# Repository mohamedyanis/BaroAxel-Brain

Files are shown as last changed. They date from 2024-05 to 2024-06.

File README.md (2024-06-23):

# BaroAxel Brain

StandWithPalestineBadgeBordered (https://techforpalestine.org/learn-more)




This Printed Circuit Board (PCB) is based on the STM32 microcontroller as well as MEMS sensors (MPU6050 and BMP280).
The PCB is designed using the free and open source software <a href="https://github.com/KiCad">KiCad</a>. 

## More Details
BaroAxel Brain is a compact Printed Circuit Board (PCB) designed for industrial instrumentation applications. It integrates the STM32L0 series microcontroller, MPU6050 accelerometer, and BMP280 barometer, providing a comprehensive solution for asynchronous motor anomaly detection and other MEMS-based applications.

This board operates with a wide input voltage range from 4.75V to 12V, ensuring compatibility with various power sources commonly found in industrial environments. It features multiple connectors for UART communication, analog-to-digital conversion, and timer functions, offering flexibility for interfacing with diverse sensors and peripherals.

The STM32L0 MCU, renowned for its low-power operation and high-performance computing capabilities, drives the board's functionality. The integrated MPU6050 accelerometer enables precise measurement of acceleration, essential for monitoring vibrations and detecting anomalies in industrial machinery. Additionally, the BMP280 barometer facilitates accurate measurement of atmospheric pressure, enabling environmental monitoring in diverse industrial settings.

The compact design of BaroAxel Brain optimizes space utilization, making it suitable for integration into space-constrained industrial systems while maximizing functionality. It also includes an SWD connector for firmware updates, ensuring easy maintenance and scalability of the board.

This combination of features makes BaroAxel Brain an ideal choice for applications requiring robust industrial instrumentation, such as asynchronous motor anomaly detection and drone instrumentation, among others.

This board is designed back to 2021, ordered in 2023, and hand soldered in April 2024<br><br>

## Features :dart:
* [x] Four layers PCB
* [x] Low power
* [x] Small size (50x50mm)
* [x] Very easy to use

## Thank _You_!
Please :star: this repo to help us improve the quality.
<br><br>

## PCB Block Diagram
PCB System Block
:---------------------:
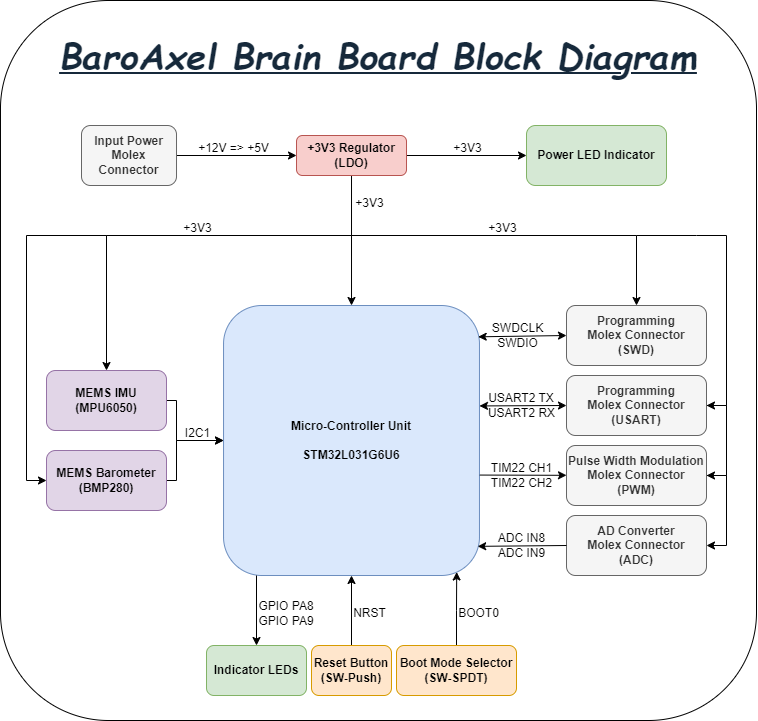
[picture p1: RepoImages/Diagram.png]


## 3D Viewer
Front View           | Back View
:---------------------:|:------------------:
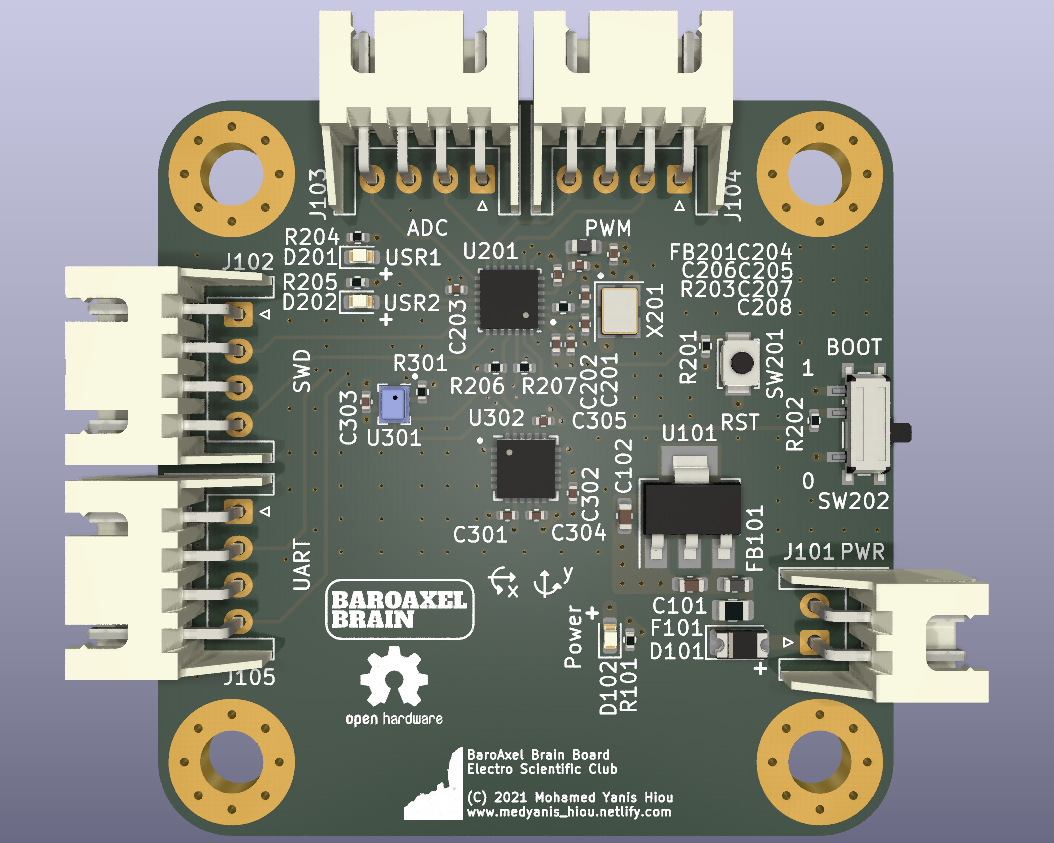
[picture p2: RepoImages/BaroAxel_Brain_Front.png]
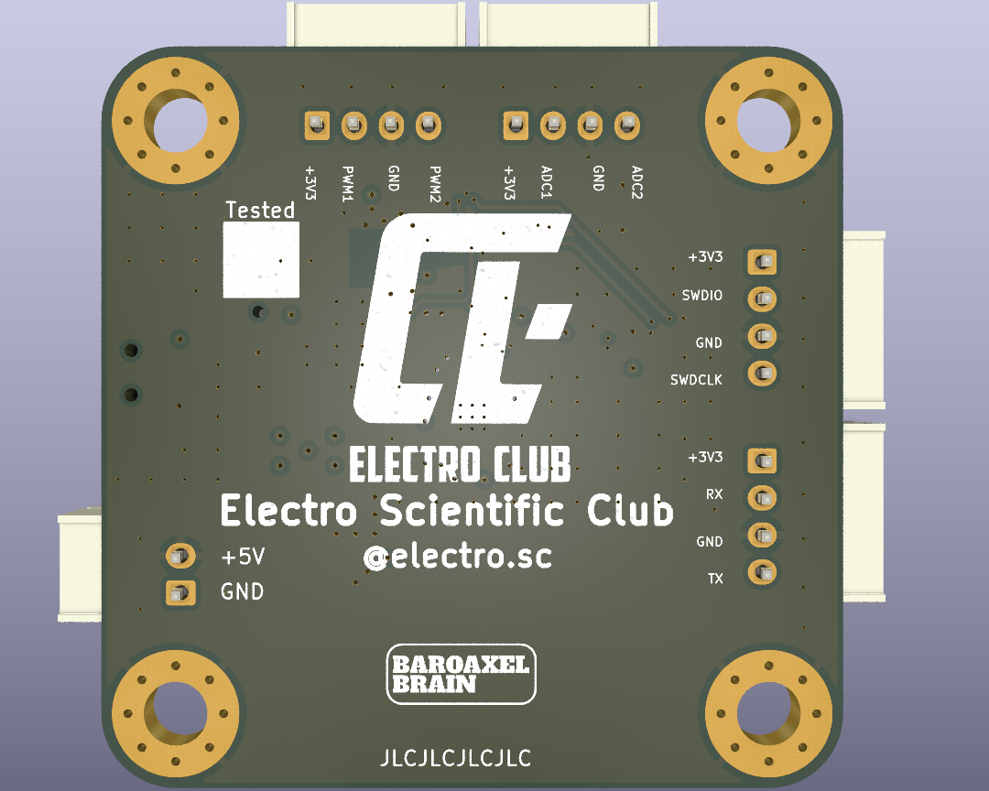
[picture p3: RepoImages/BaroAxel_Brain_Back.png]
 | 
Side View 1         |  Side View 2
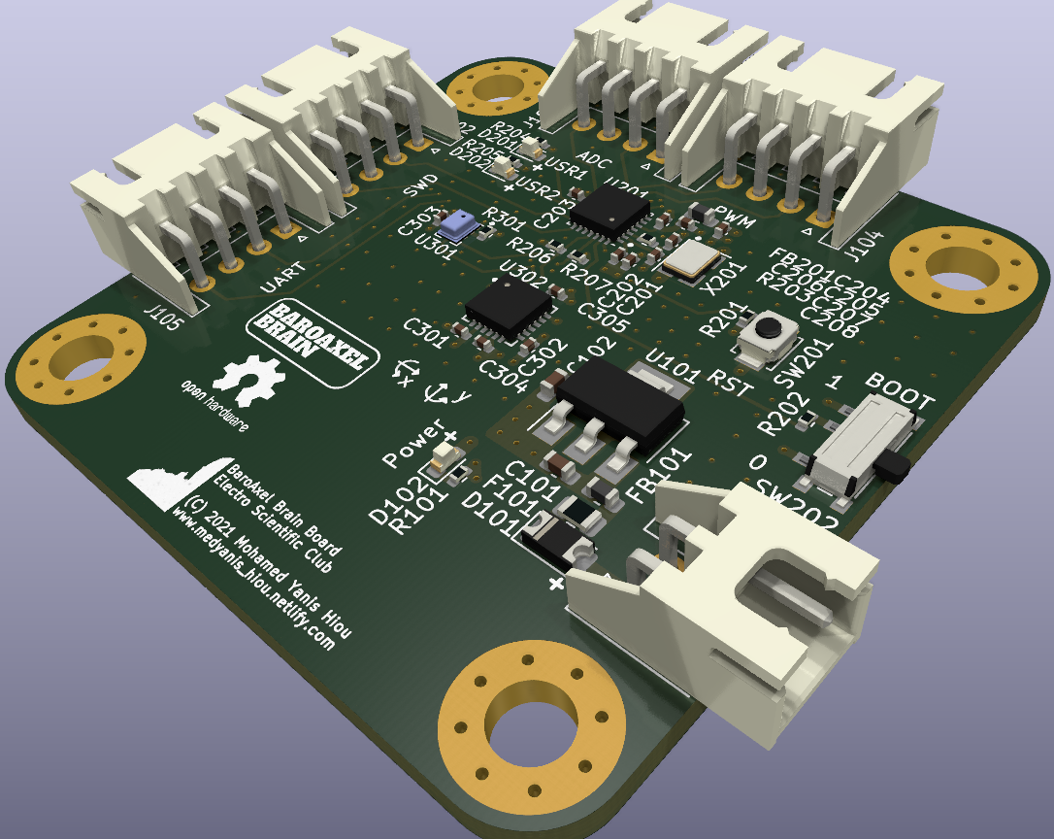
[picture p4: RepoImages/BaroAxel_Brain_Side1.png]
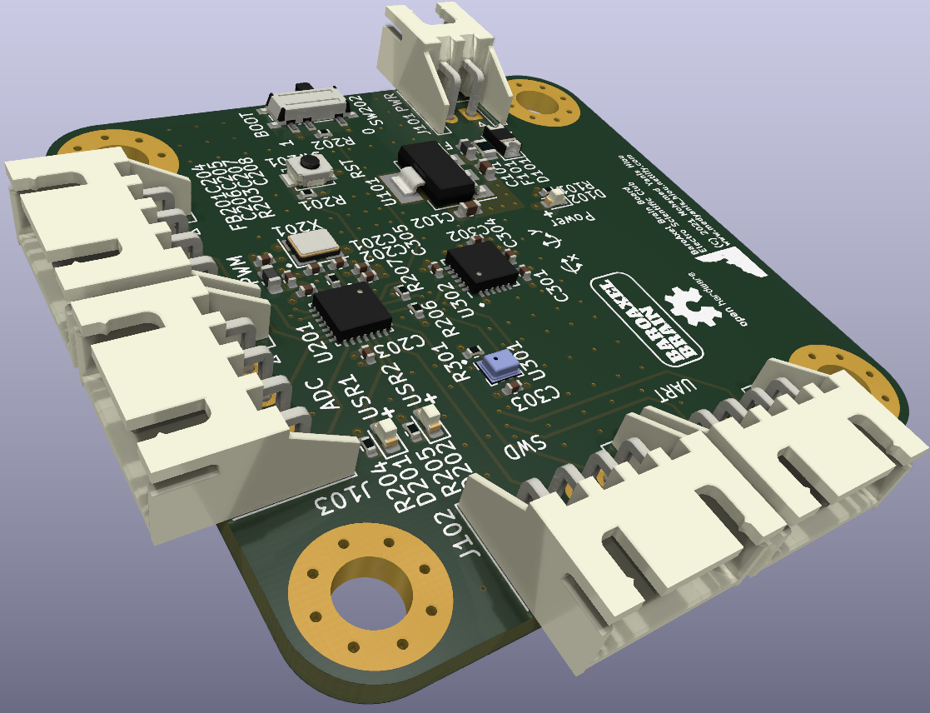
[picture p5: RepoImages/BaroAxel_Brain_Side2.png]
 | 
Side View 3         |  Side View 4
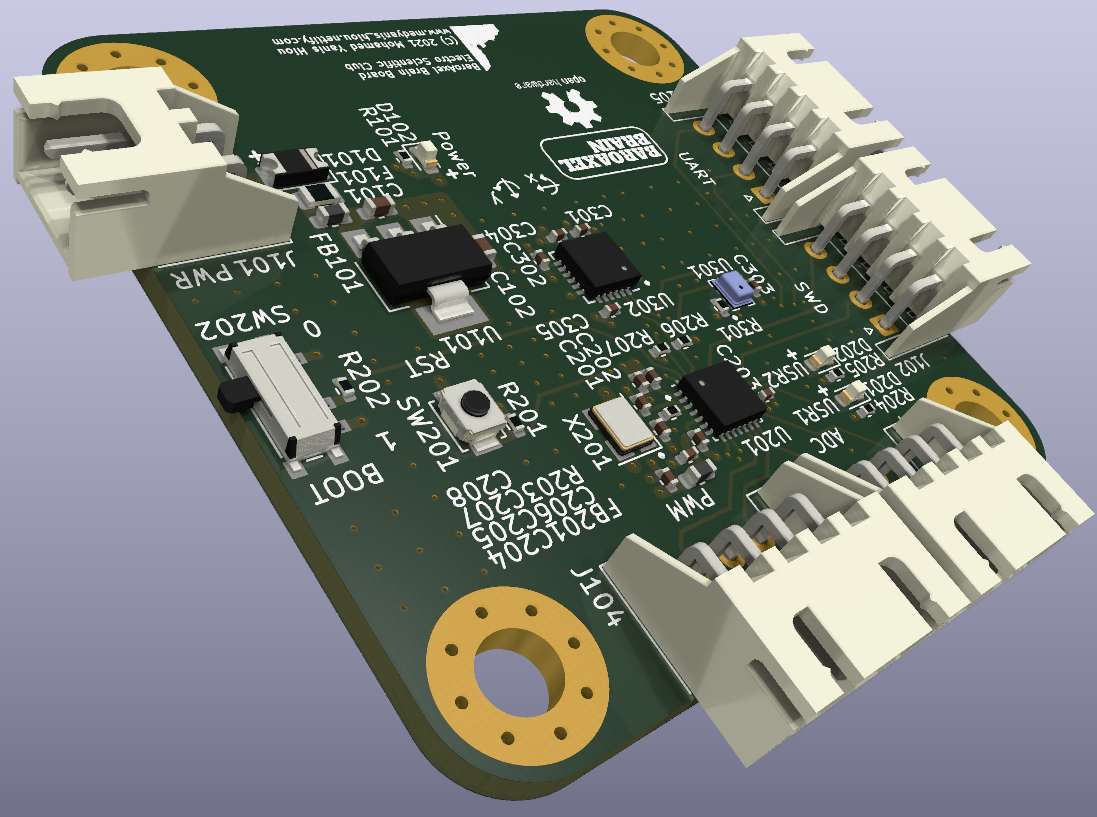
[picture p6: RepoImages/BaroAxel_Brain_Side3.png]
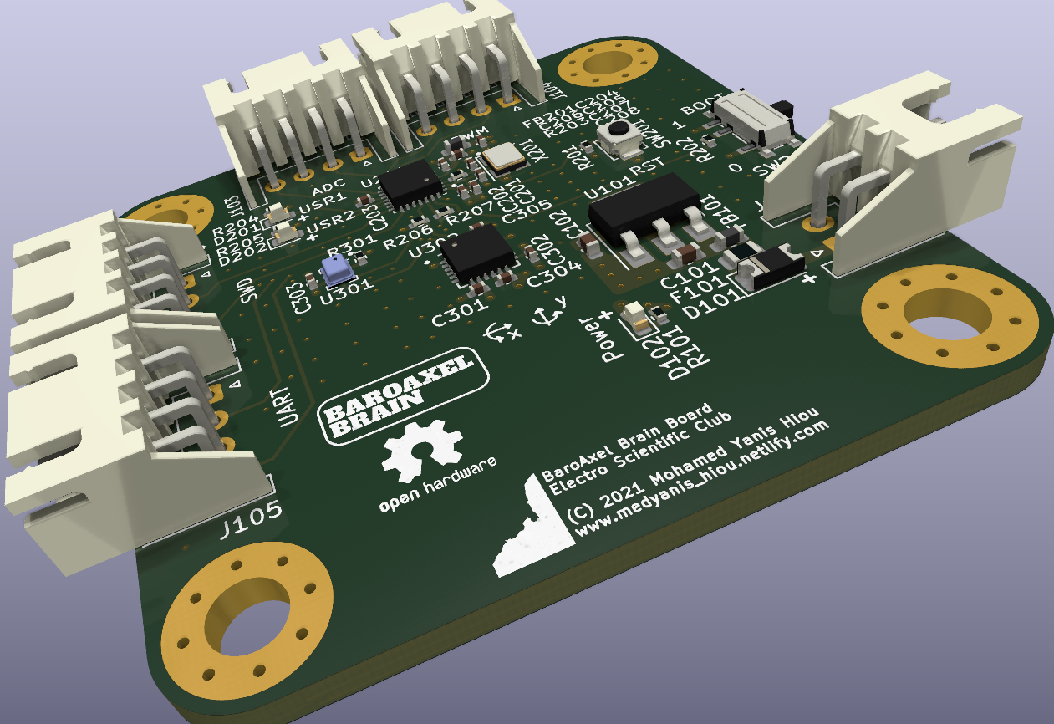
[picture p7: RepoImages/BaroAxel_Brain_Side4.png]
 | 

## Before, During and After Soldering
Before 1            | Before 2
:---------------------:|:------------------:
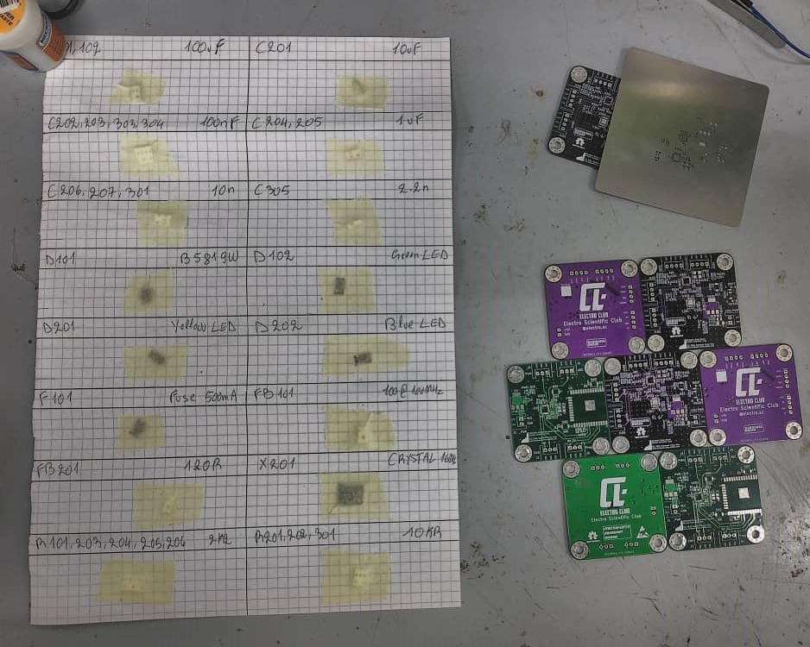
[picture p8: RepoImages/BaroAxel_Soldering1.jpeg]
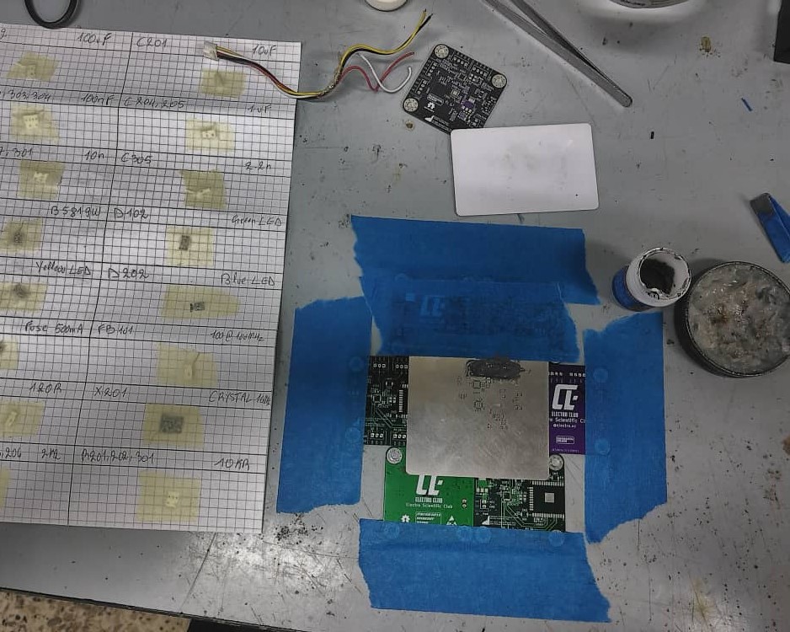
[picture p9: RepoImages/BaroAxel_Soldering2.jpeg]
 | 
During 1         |  During 2
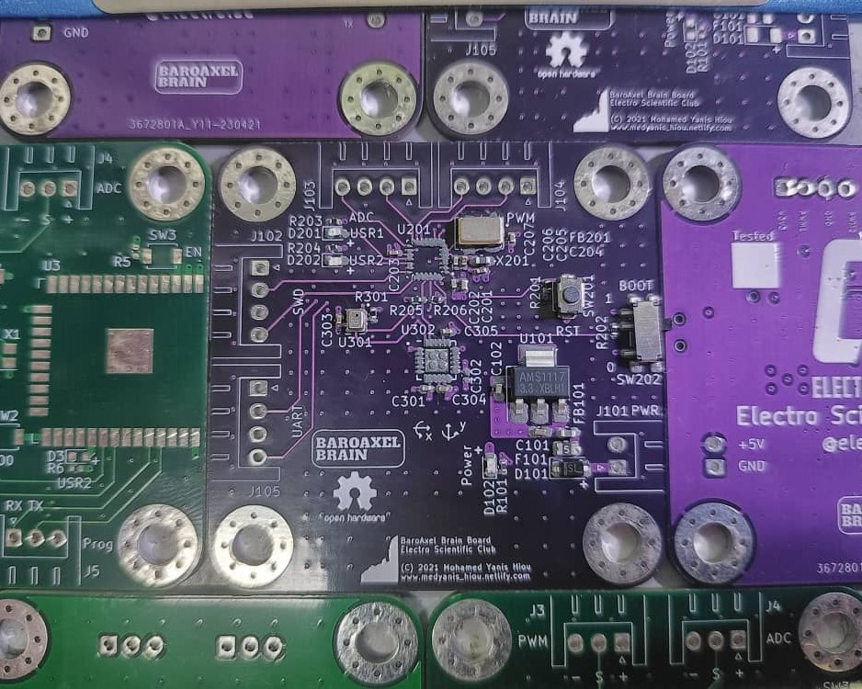
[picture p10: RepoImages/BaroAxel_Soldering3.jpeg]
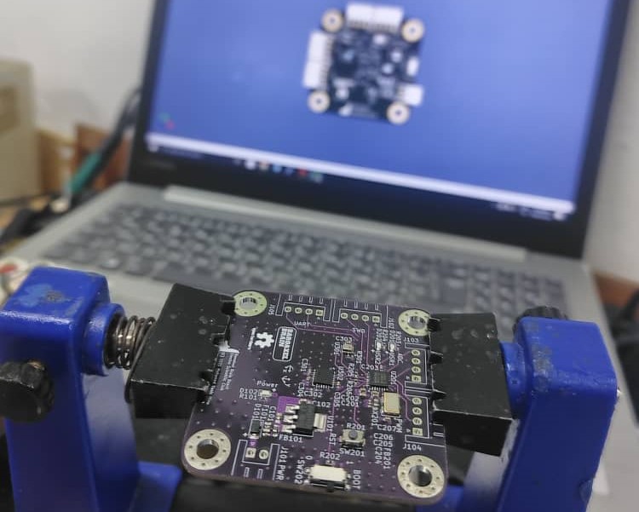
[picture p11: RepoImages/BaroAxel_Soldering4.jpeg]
 | 
After 1         |  After 2
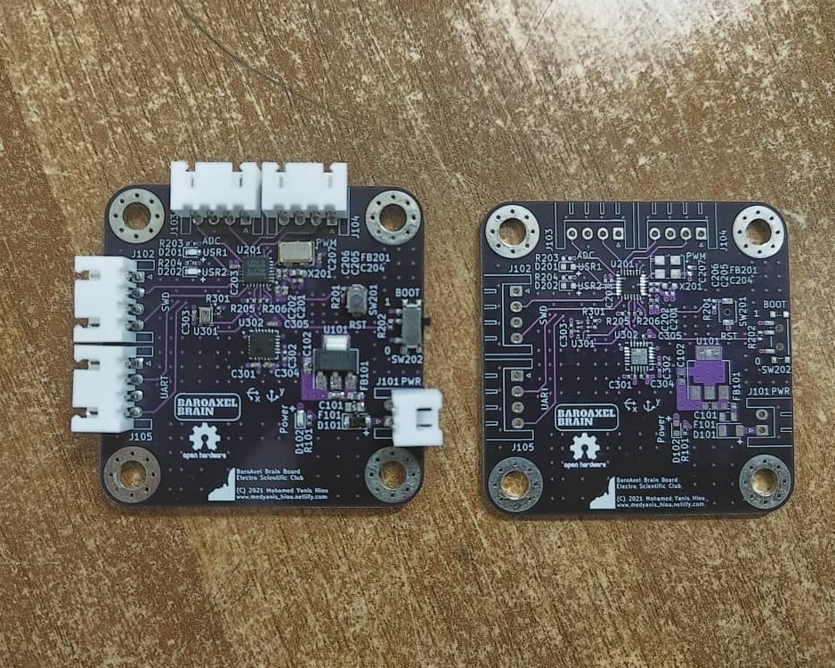
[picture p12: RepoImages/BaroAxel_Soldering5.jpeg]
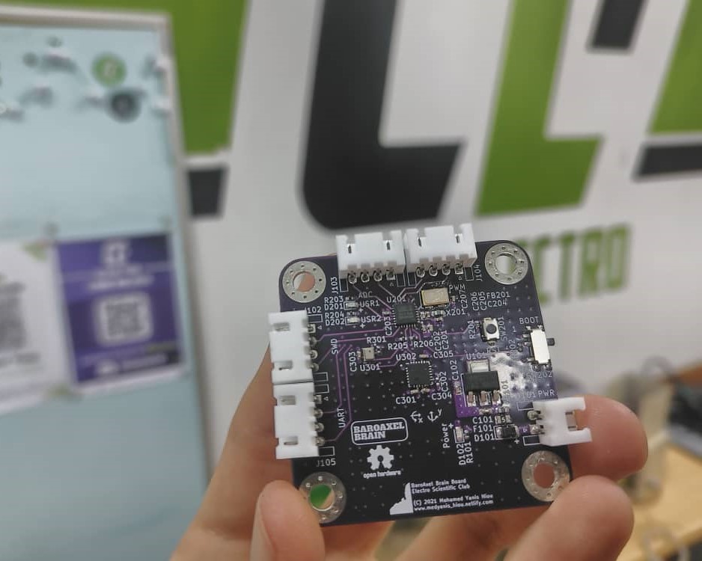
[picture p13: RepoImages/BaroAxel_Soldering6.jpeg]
 | 

## Testing the Functionality
Here I tested the functionality of the board after assembling it. I tested the built-in LEDs and the IMU (MPU6050) using I2C protocol, and print some texts on the laptop's screen using putty application via the UART-TTL converter.<br><br>


## 3D Enclosure Design
Here is the 3D Enclosure I designed using SolidWorks. The design contains the top and bottom pieces as well as a small glass plate just to show the electronics inside. Of course assembled with SolidWorks Assembly.
See the folder [3D](3D) in order to get the designs and print the parts using a 3D Printer.<br><br>
Enclosure Top           | Enclosure Bottom
:---------------------:|:------------------:
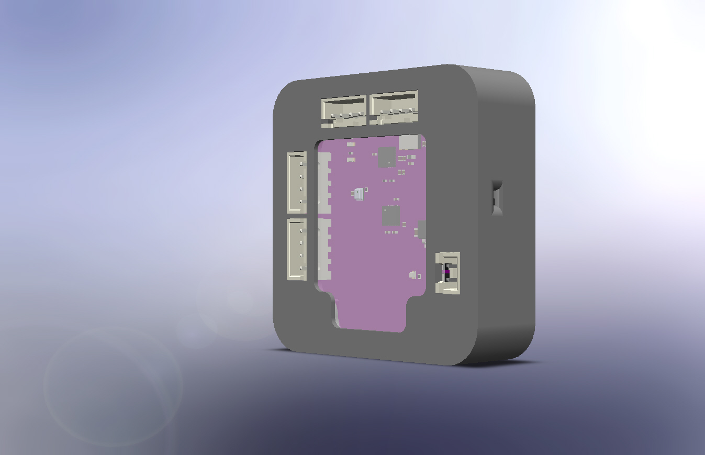
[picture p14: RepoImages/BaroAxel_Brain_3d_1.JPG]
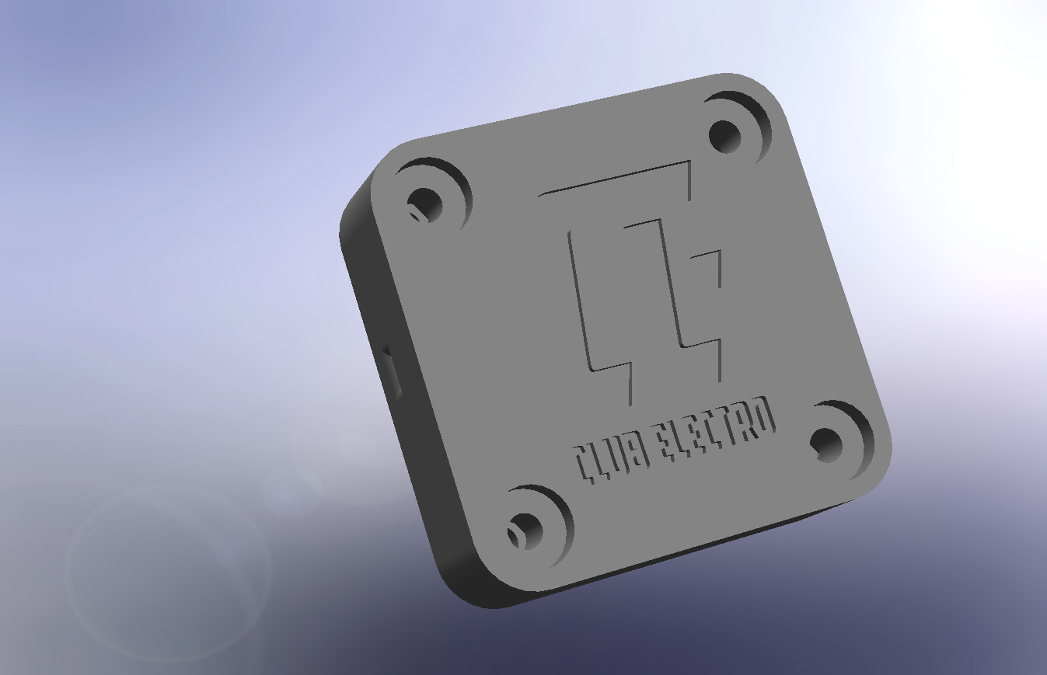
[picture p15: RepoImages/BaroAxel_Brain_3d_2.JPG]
 | 
Enclosure Side 1         |  Enclosure Side 2
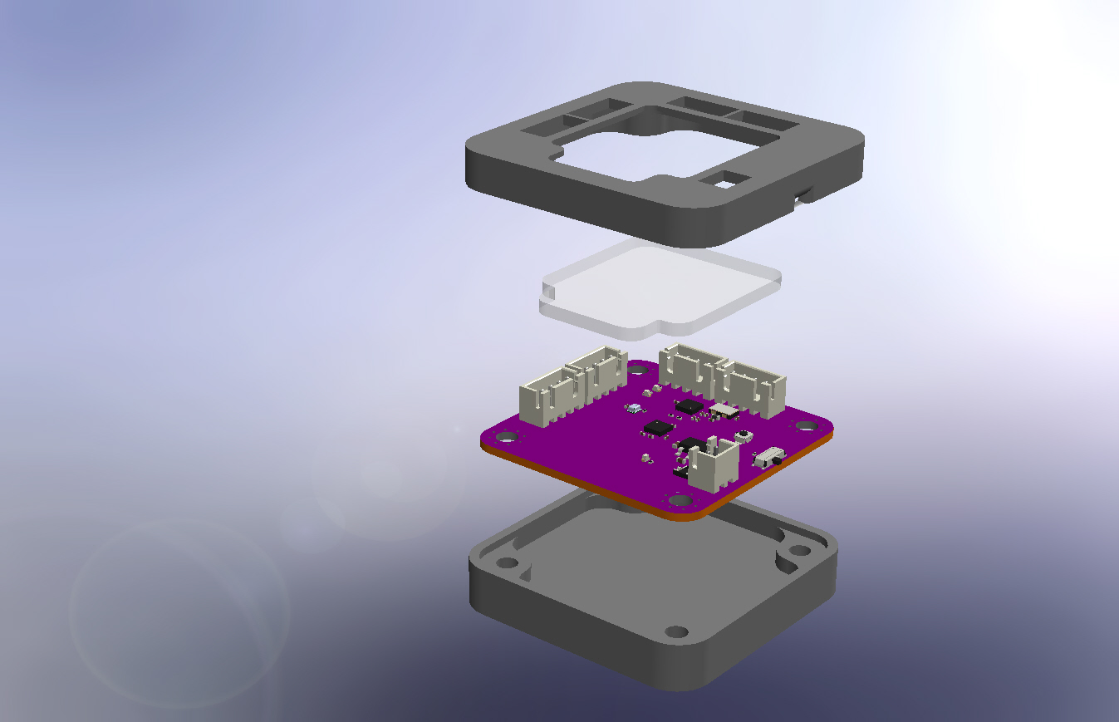
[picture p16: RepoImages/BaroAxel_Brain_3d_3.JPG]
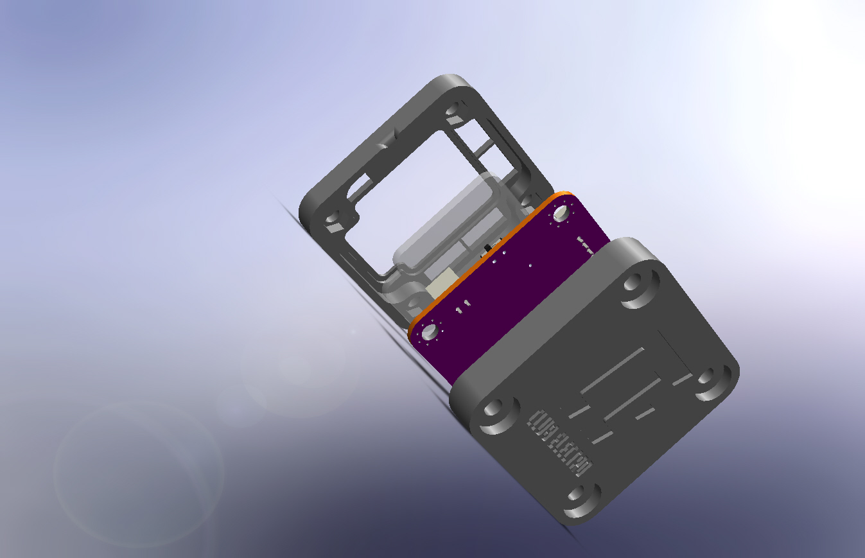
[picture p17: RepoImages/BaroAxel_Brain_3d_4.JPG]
 | 

## Requirements

If you want to review the PCB or yoou wanna edit the schematics/layout, yoou only need to install KiCad software to your machine.

* Go to the <a href="https://www.kicad.org/download/">Official KiCad Download Page</a>.
* Select your operating system.
* Download the executable file and install it.

## Documentations
Open the [Datasheets](Datasheets) folder and you will find all the datasheets, applications notes, and design guidelines that help you understand the design better.

## How To Use It

1. Install this repository, click <a href="https://github.com/mohamedyanis/BaroAxel-Brain/archive/master.zip"> here </a> to install it. Or use git command:
```bach
git clone https://github.com/mohamedyanis/BaroAxel-Brain.git
```
3. Extract the folder and open it.
4. Navigate for the [Manufacturing](Manufacturing) folder.
5. Go to your best PCB manufacturer website and click on quote.
6. Upload the [BaroAxel_Brain_Gerber.rar](Manufacturing/Gerber/BaroAxel_Brain_Gerber.zip) in order to order the board.

## License
The content of this project is licenced under the [BSD 3-Clause "New" or "Revised" License](LICENSE).

## Contributing 💡
If you want to contribute to this project and make it better with new ideas, your pull request is very welcomed.<br>
If you find any issue just put it in the repository issue section, thanks!<br><br>
.سبحَانَكَ اللَّهُمَّ وَبِحَمْدِكَ، أَشْهَدُ أَنْ لا إِلهَ إِلأَ انْتَ أَسْتَغْفِرُكَ وَأَتْوبُ إِلَيْكَ

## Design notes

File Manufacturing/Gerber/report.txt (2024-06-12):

Plotted to 'F:\Documents\Kicad\KiCad 6\BaroAxel_Brain_Board\Manufacturing\Gerber\BaroAxel_Brain-F_Cu.gbr'.
Plotted to 'F:\Documents\Kicad\KiCad 6\BaroAxel_Brain_Board\Manufacturing\Gerber\BaroAxel_Brain-In1_Cu.gbr'.
Plotted to 'F:\Documents\Kicad\KiCad 6\BaroAxel_Brain_Board\Manufacturing\Gerber\BaroAxel_Brain-In2_Cu.gbr'.
Plotted to 'F:\Documents\Kicad\KiCad 6\BaroAxel_Brain_Board\Manufacturing\Gerber\BaroAxel_Brain-B_Cu.gbr'.
Plotted to 'F:\Documents\Kicad\KiCad 6\BaroAxel_Brain_Board\Manufacturing\Gerber\BaroAxel_Brain-F_Paste.gbr'.
Plotted to 'F:\Documents\Kicad\KiCad 6\BaroAxel_Brain_Board\Manufacturing\Gerber\BaroAxel_Brain-B_Paste.gbr'.
Plotted to 'F:\Documents\Kicad\KiCad 6\BaroAxel_Brain_Board\Manufacturing\Gerber\BaroAxel_Brain-F_Silkscreen.gbr'.
Plotted to 'F:\Documents\Kicad\KiCad 6\BaroAxel_Brain_Board\Manufacturing\Gerber\BaroAxel_Brain-B_Silkscreen.gbr'.
Plotted to 'F:\Documents\Kicad\KiCad 6\BaroAxel_Brain_Board\Manufacturing\Gerber\BaroAxel_Brain-F_Mask.gbr'.
Plotted to 'F:\Documents\Kicad\KiCad 6\BaroAxel_Brain_Board\Manufacturing\Gerber\BaroAxel_Brain-B_Mask.gbr'.
Plotted to 'F:\Documents\Kicad\KiCad 6\BaroAxel_Brain_Board\Manufacturing\Gerber\BaroAxel_Brain-Edge_Cuts.gbr'.
Created Gerber job file 'F:\Documents\Kicad\KiCad 6\BaroAxel_Brain_Board\Manufacturing\Gerber\BaroAxel_Brain-job.gbrjob'.
Info: Done.

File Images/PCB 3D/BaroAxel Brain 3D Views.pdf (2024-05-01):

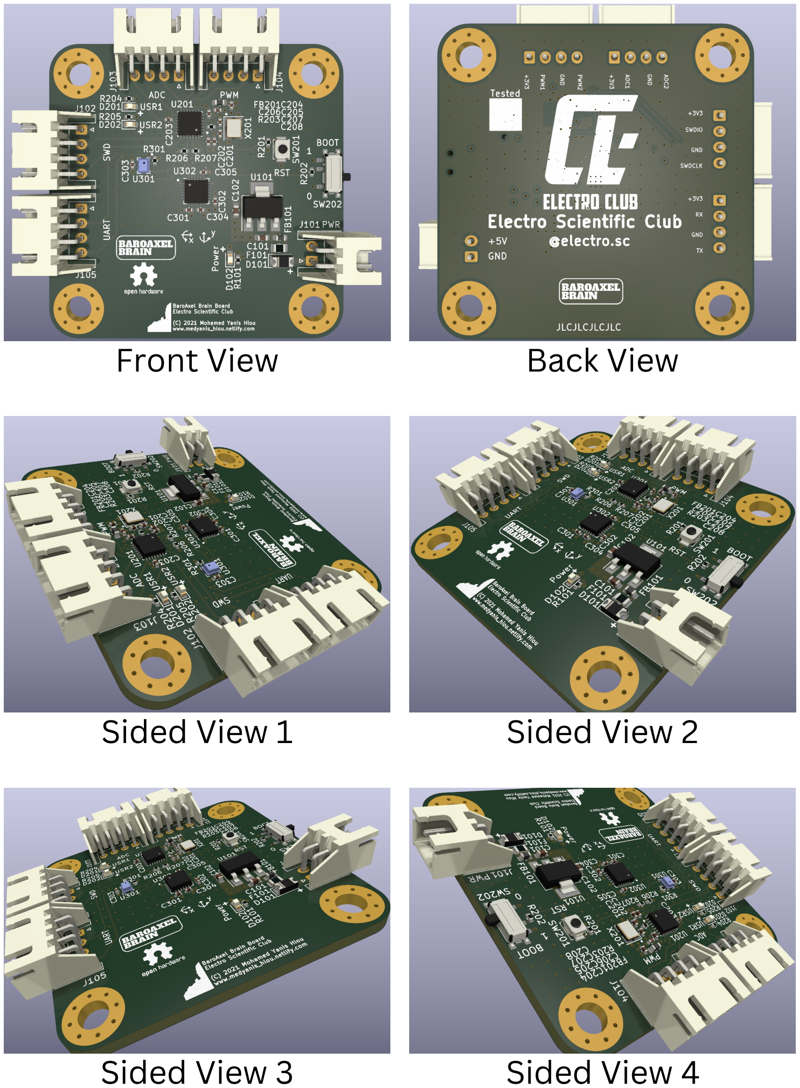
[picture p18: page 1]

Front View | Back View
Sided View 1 | Sided View 2
Sided View 3 | Sided View 4

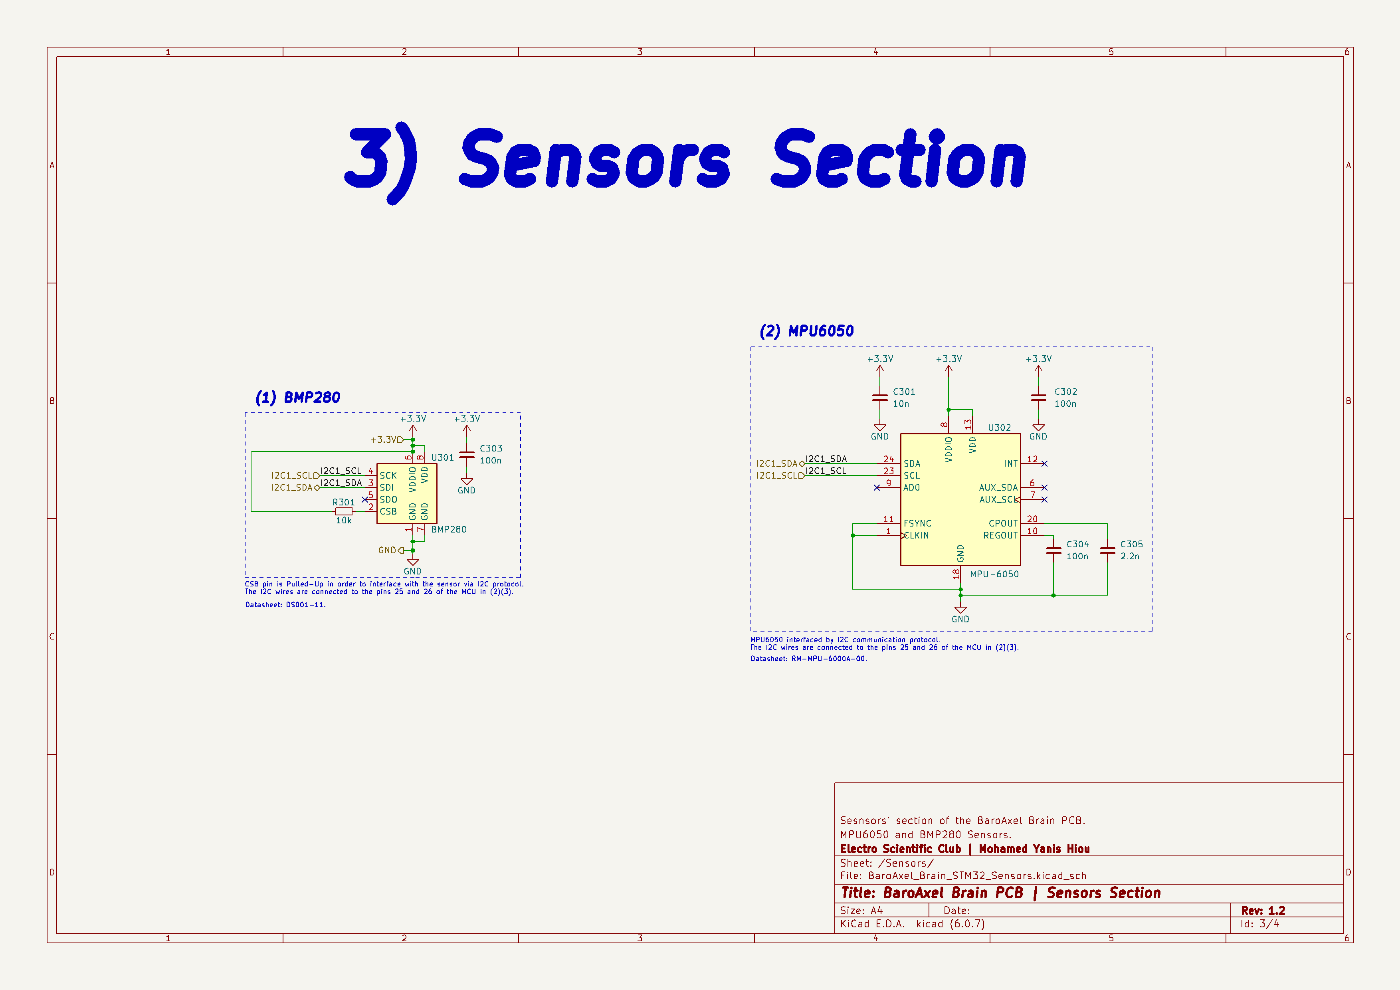
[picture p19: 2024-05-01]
Images/Schematics/4-Sensors.png

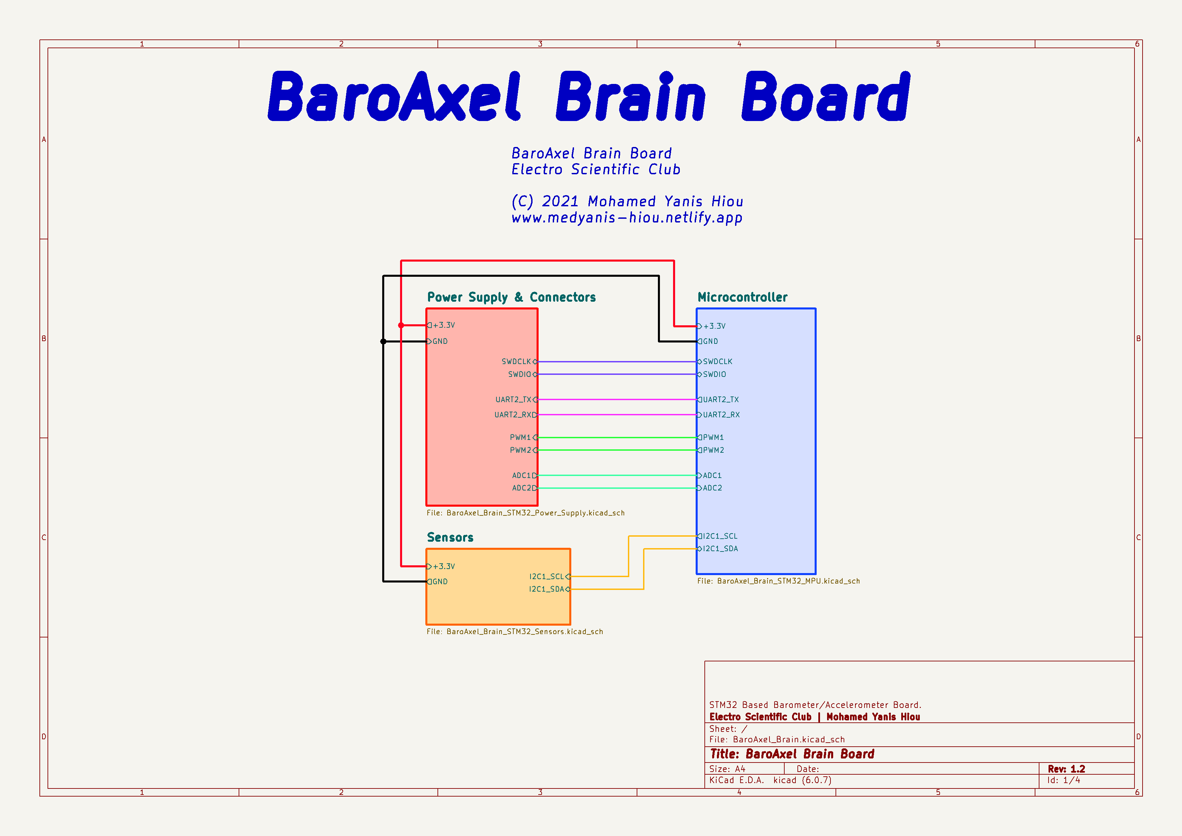
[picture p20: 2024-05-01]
Images/Schematics/1-BaroAxel-Brain.png

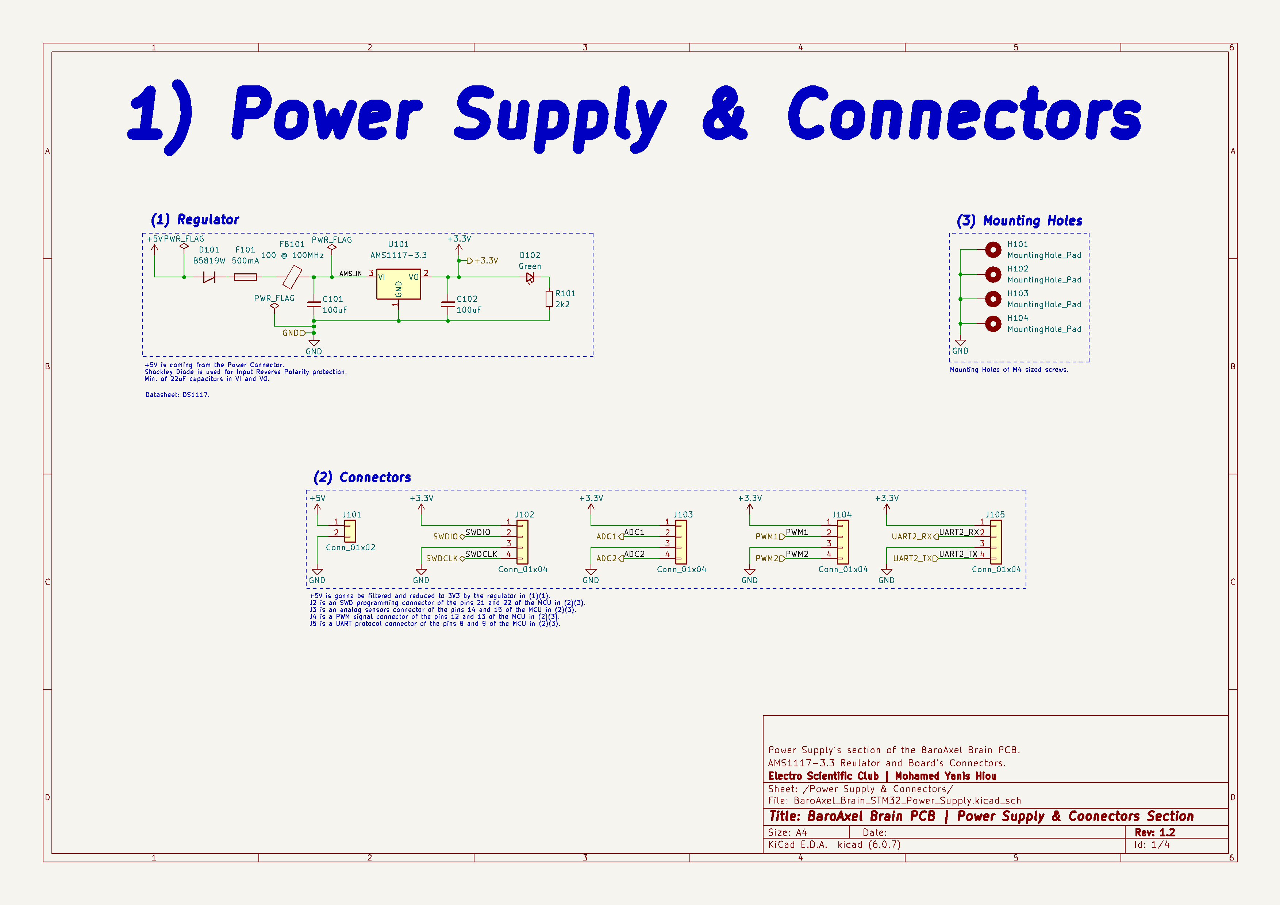
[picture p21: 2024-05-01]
Images/Schematics/2-Power-Supply-&-Connectors.png

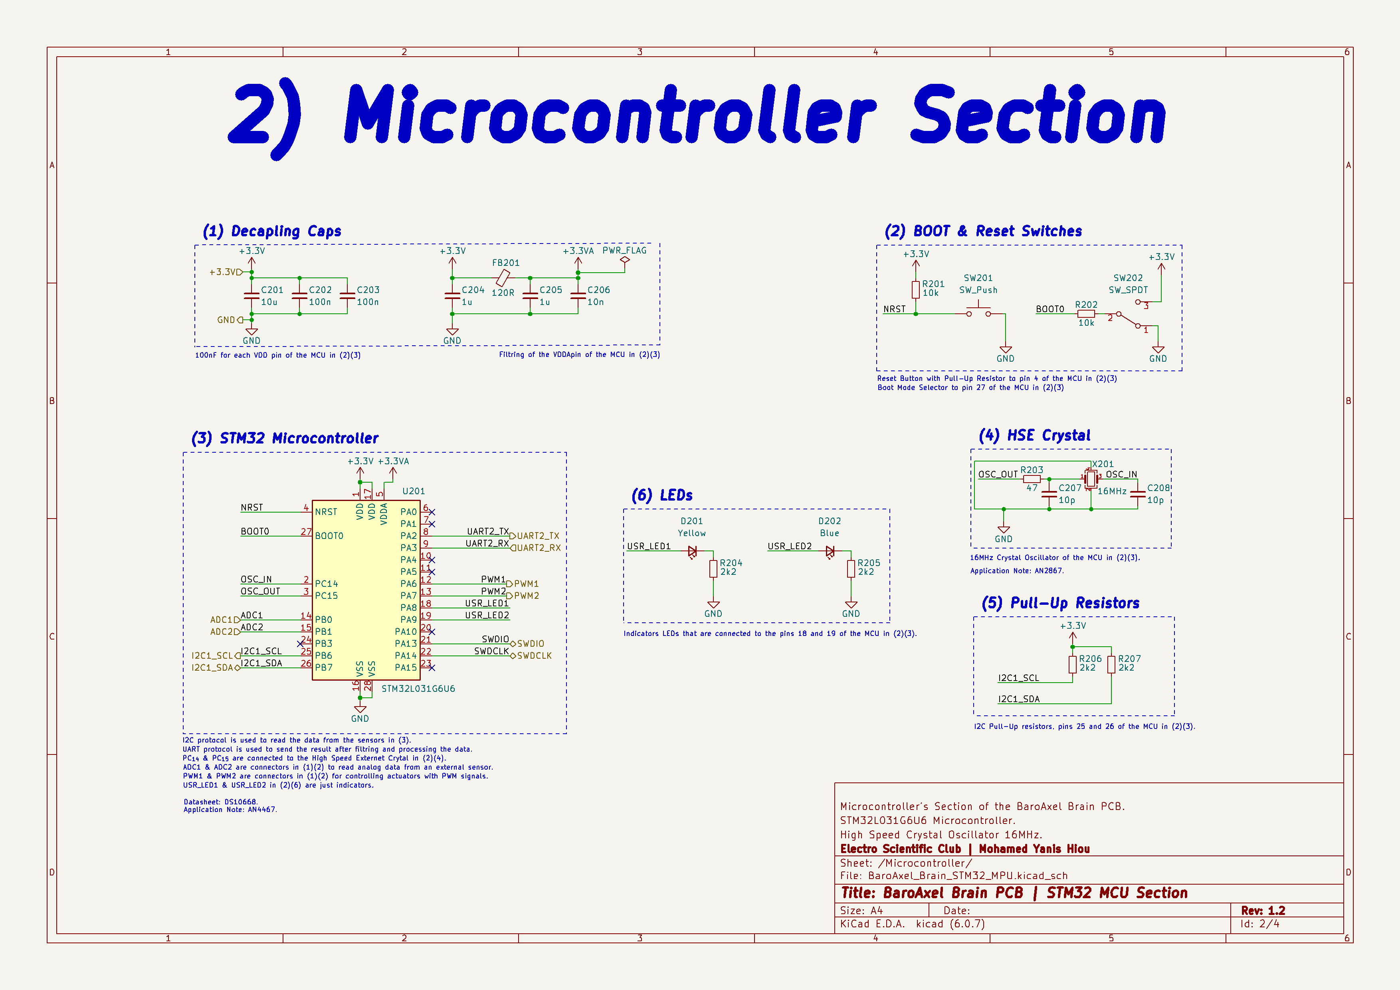
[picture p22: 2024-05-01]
Images/Schematics/3-Microcontroller.png

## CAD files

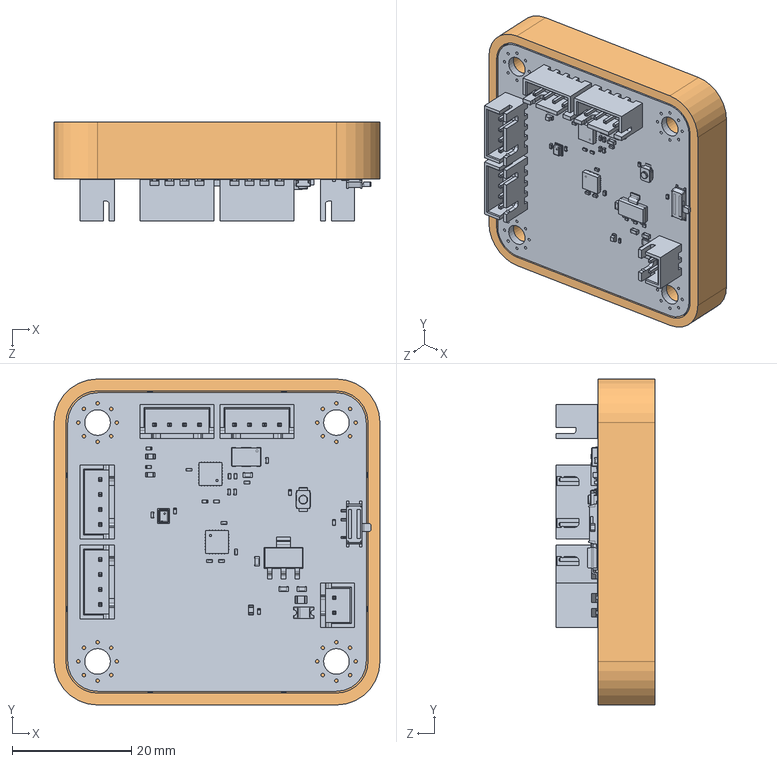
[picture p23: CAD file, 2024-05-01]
3D/SolidWorks/BaroAxel_Brain_VerticalJST_Assembly.SLDASM
54.6 x 54.6 x 16.6 mm
BaroAxel_Brain_VerticalJST_PCB
BaroAxel_Brain_VerticalJST_Bottom

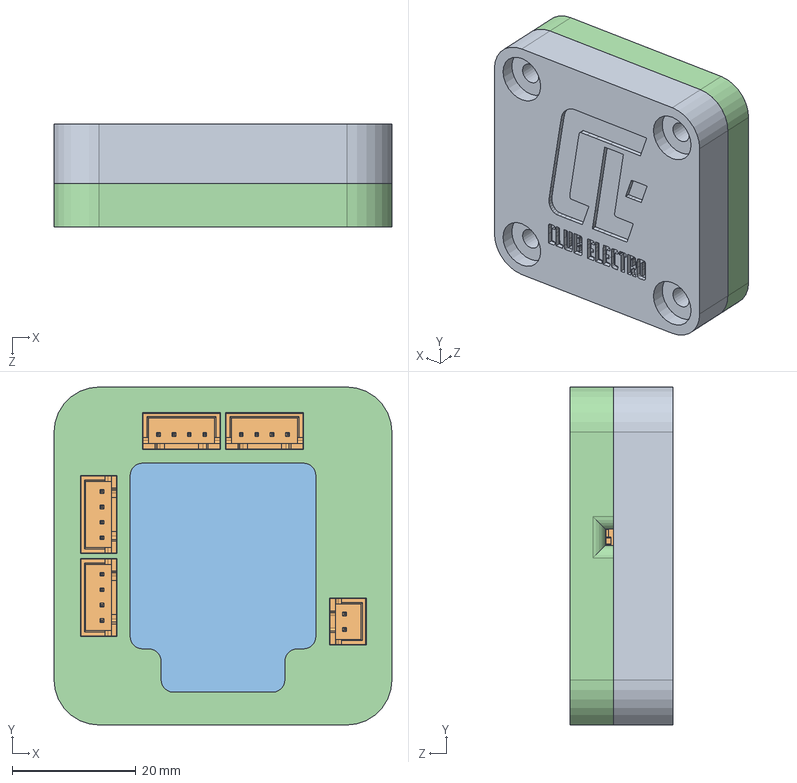
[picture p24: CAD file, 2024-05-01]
3D/SolidWorks/BaroAxel_Brain_VerticalJST_Assembly_Full.SLDASM
54.6 x 54.6 x 16.6 mm
BaroAxel_Brain_VerticalJST_Bottom
BaroAxel_Brain_VerticalJST_PCB
BaroAxel_Brain_VerticalJST_Glass
BaroAxel_Brain_VerticalJST_Top

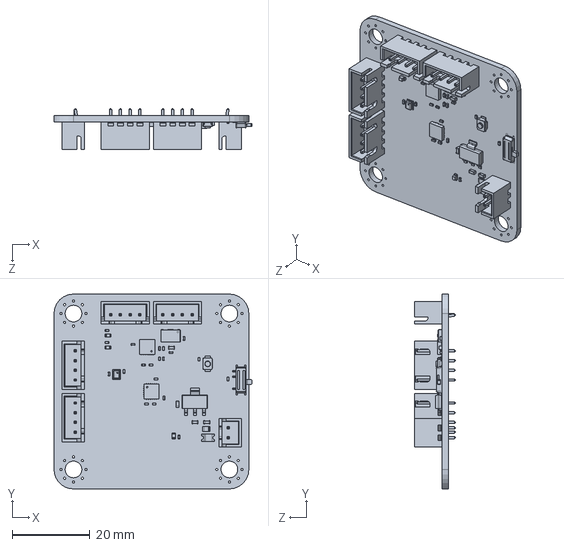
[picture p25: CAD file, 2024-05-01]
3D/BaroAxel_Brain_VerticalJST_PCB.SLDPRT
50.8 x 50.0 x 10.4 mm

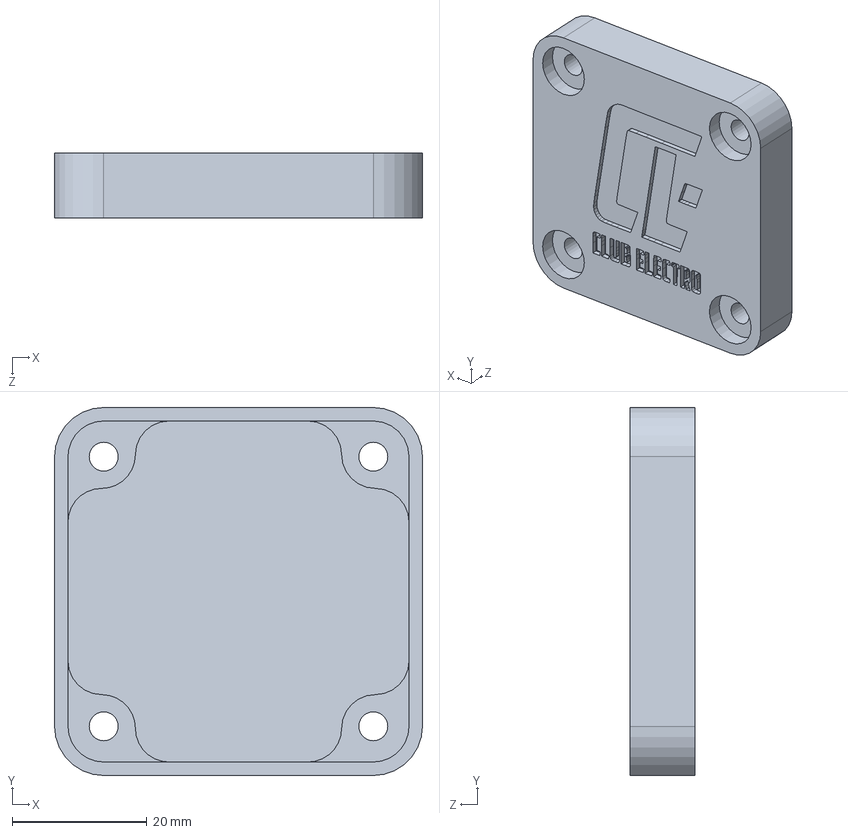
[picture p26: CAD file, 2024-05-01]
3D/SolidWorks/BaroAxel_Brain_VerticalJST_Bottom.SLDPRT
54.6 x 54.6 x 9.59 mm

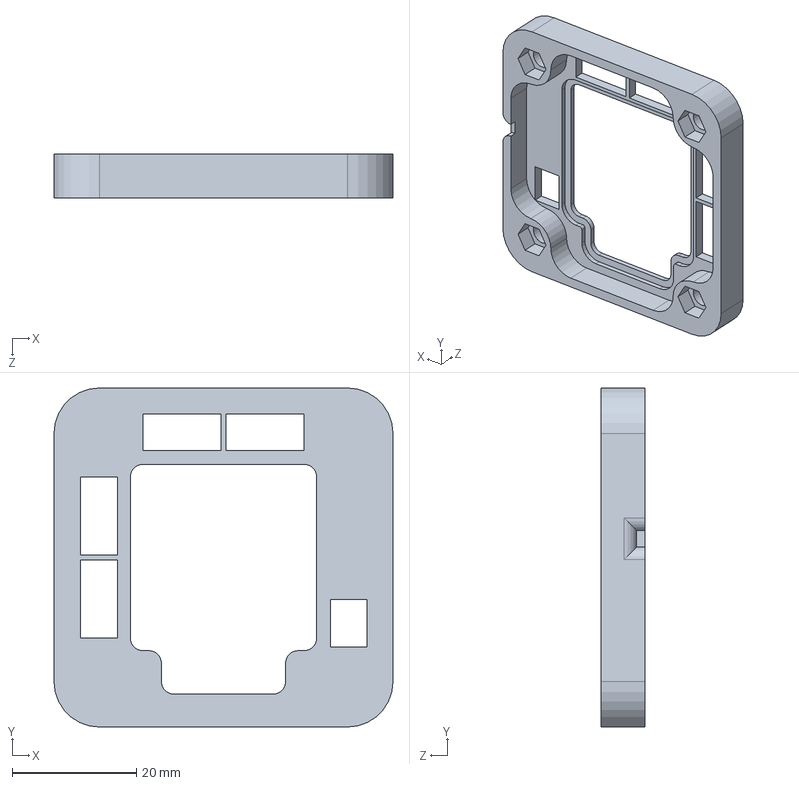
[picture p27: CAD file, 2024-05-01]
3D/SolidWorks/BaroAxel_Brain_VerticalJST_Top.SLDPRT
54.6 x 54.6 x 7.05 mm

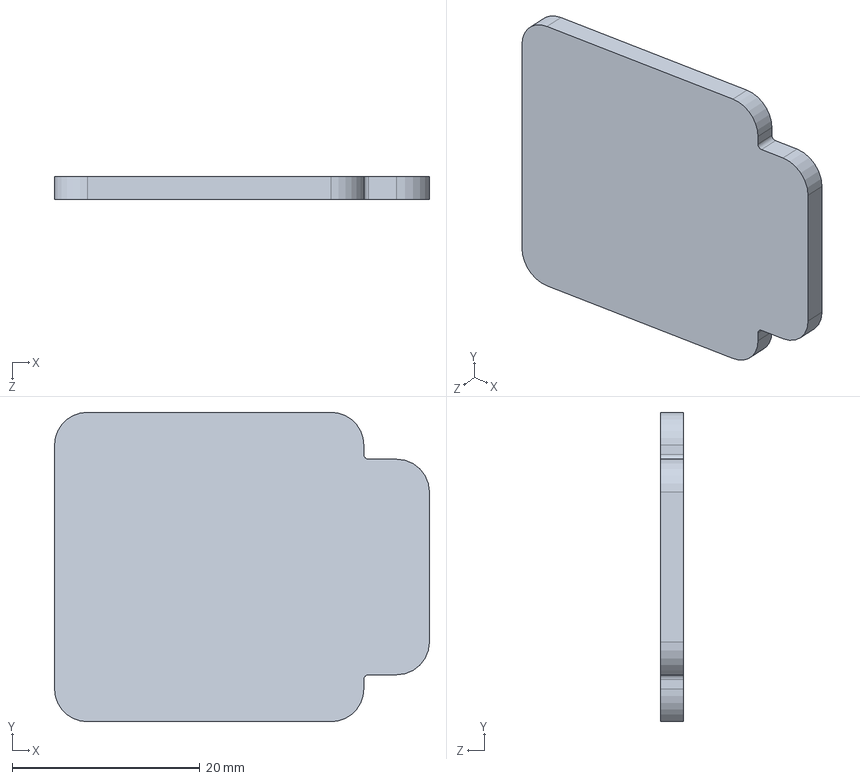
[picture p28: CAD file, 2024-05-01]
3D/SolidWorks/BaroAxel_Brain_VerticalJST_Glass.SLDPRT
40.0 x 33.0 x 2.50 mm

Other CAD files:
3D/SolidWorks/BaroAxel_Brain_VerticalJST_PCB.SLDPRT
3D/SolidWorks/STL/BaroAxel_Brain_VerticalJST_Bottom.STL
3D/SolidWorks/STL/BaroAxel_Brain_VerticalJST_Top.STL

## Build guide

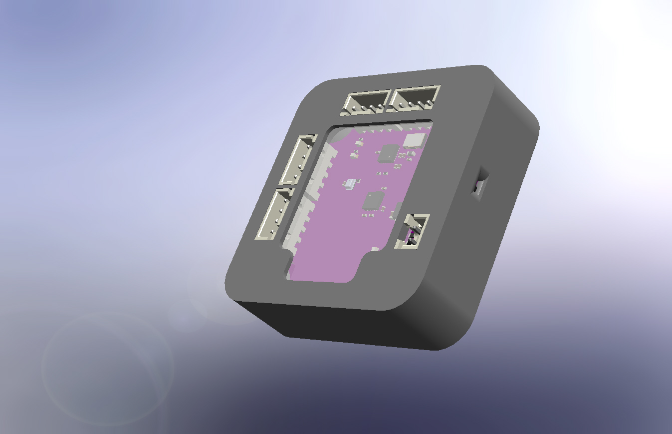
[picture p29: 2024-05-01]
3D/SolidWorks/Images/BaroAxel_Brain_VerticalJST_Assembly_Full_img3.JPG

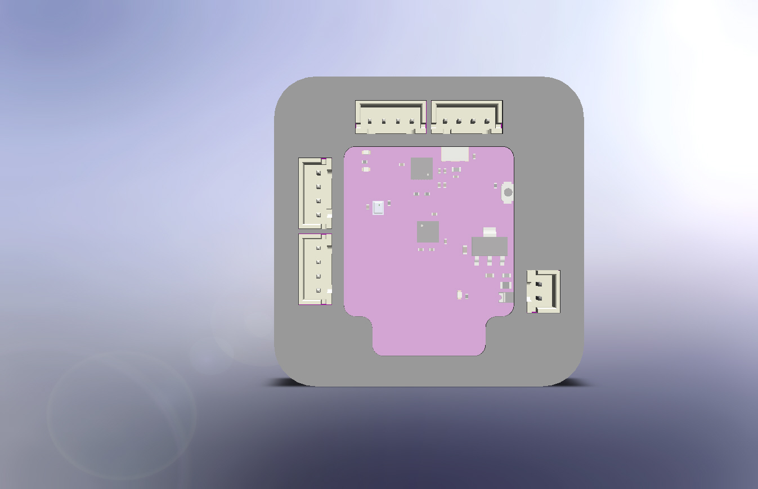
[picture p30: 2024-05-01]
3D/SolidWorks/Images/BaroAxel_Brain_VerticalJST_Assembly_Full_img1.JPG

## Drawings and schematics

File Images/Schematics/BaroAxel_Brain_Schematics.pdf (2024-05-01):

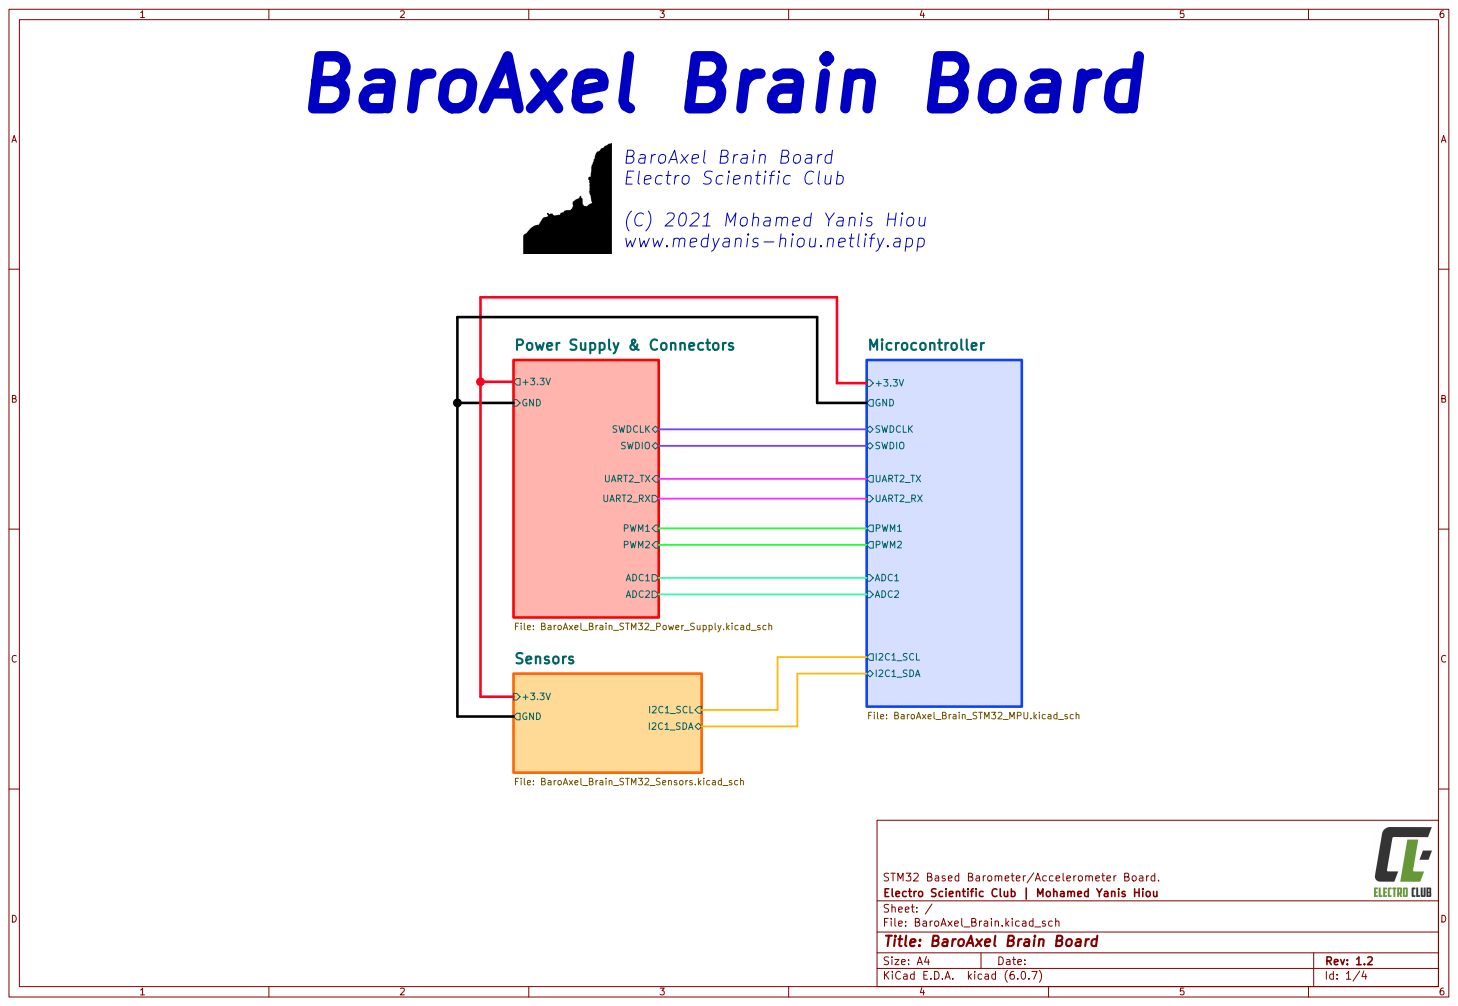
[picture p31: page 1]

(C) 2021 Mohamed Yanis Hiou
www.medyanis-hiou.netlify.app

File: BaroAxel_Brain.kicad_sch Sheet: / Electro Scientific Club | Mohamed Yanis Hiou STM32 Based Barometer/Accelerometer Board.

Id: 1/4 Title: BaroAxel Brain Board

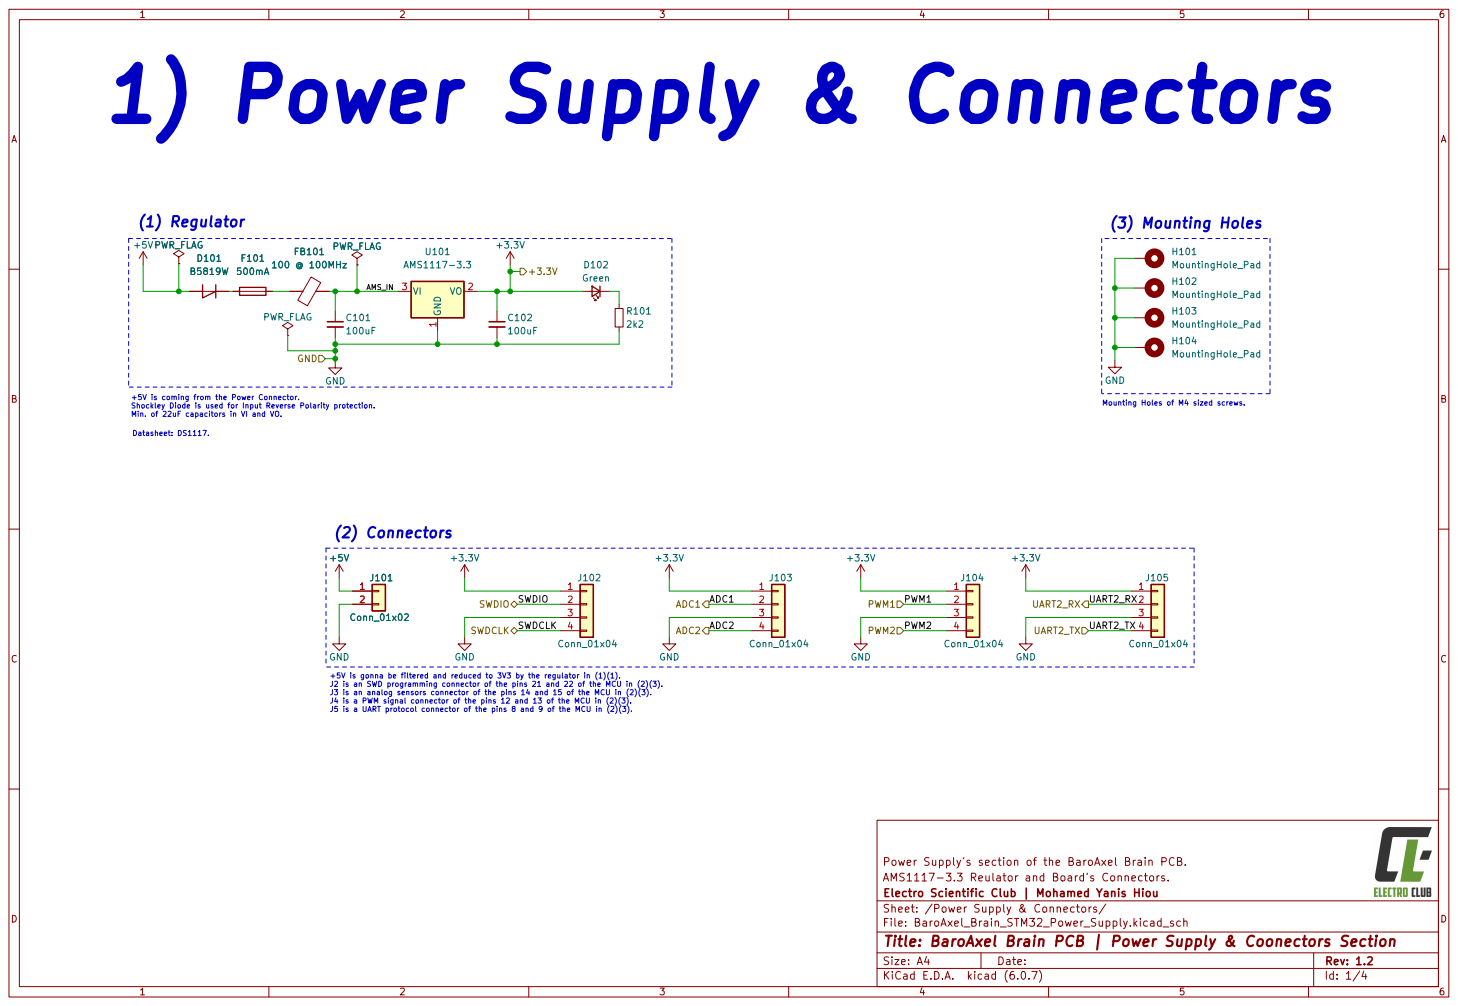
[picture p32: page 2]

+5V is gonna be filtered and reduced to 3V3 by the regulator in (1)(1). J2 is an SWD programming connector of the pins 21 and 22 of the MCU in (2)(3). J3 is an analog sensors connector of the pins 14 and 15 of the MCU in (2)(3). J4 is a PWM signal connector of the pins 12 and 13 of the MCU in (2)(3). J5 is a UART protocol connector of the pins 8 and 9 of the MCU in (2)(3). (2) Connectors

Electro Scientific Club | Mohamed Yanis Hiou AMS1117-3.3 Reulator and Board's Connectors. Power Supply's section of the BaroAxel Brain PCB.

Sheet: /Power Supply & Connectors/
File: BaroAxel_Brain_STM32_Power_Supply.kicad_sch
Id: 1/4 Title: BaroAxel Brain PCB | Power Supply & Coonectors Section

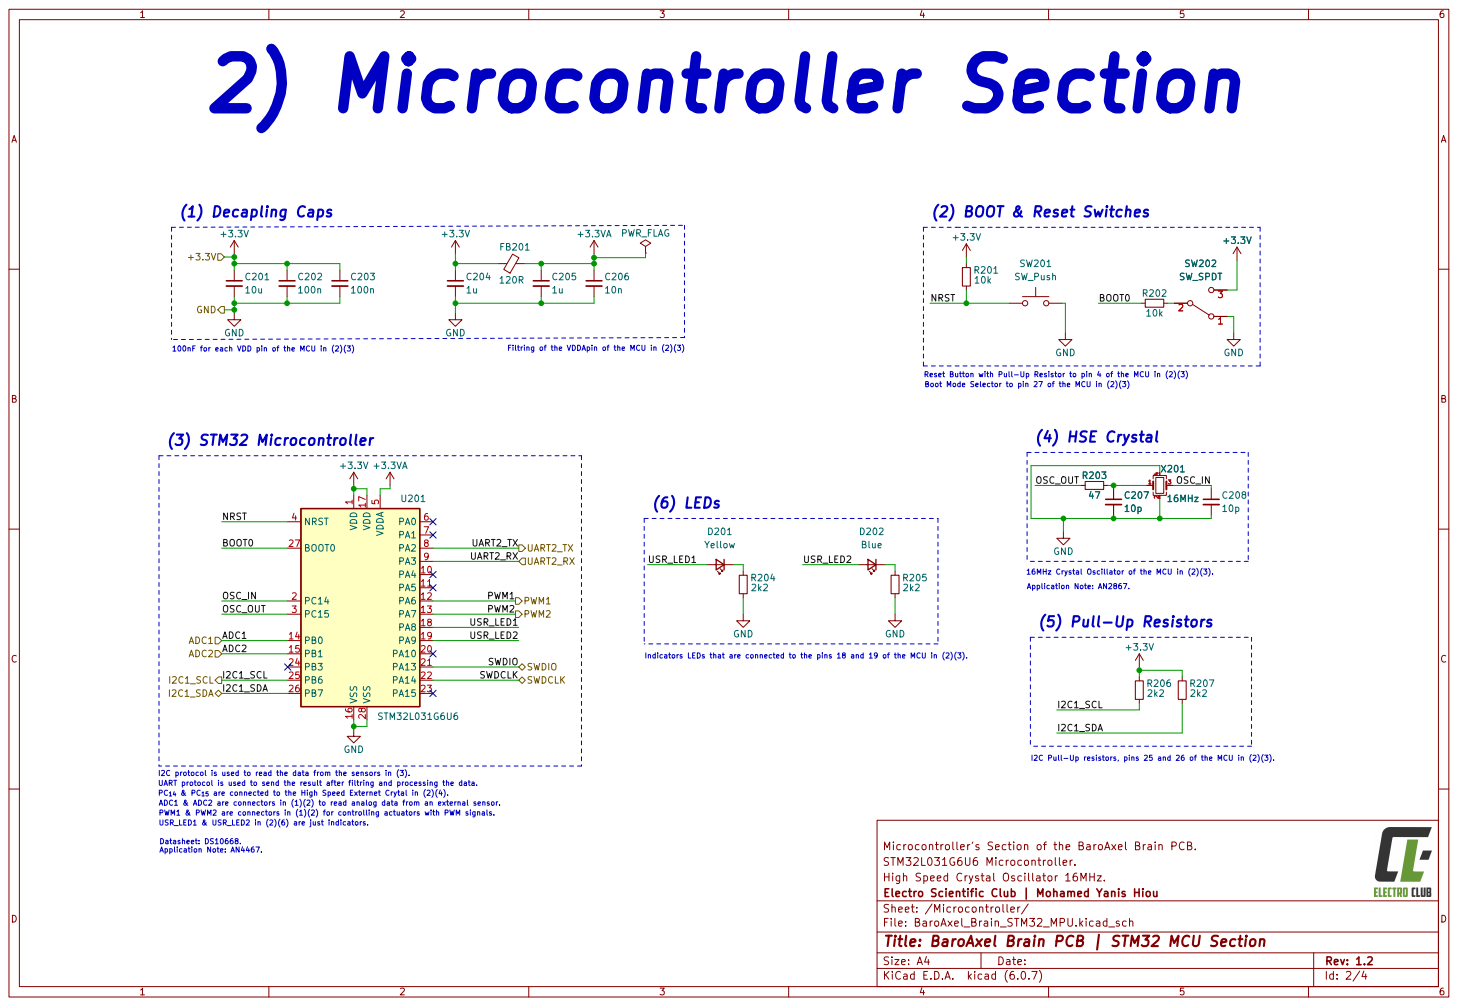
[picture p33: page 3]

100nF for each VDD pin of the MCU in (2)(3) UART protocol is used to send the result after filtring and processing the data.

Filtring of the VDDApin of the MCU in (2)(3)

Reset Button with Pull-Up Resistor to pin 4 of the MCU in (2)(3) Boot Mode Selector to pin 27 of the MCU in (2)(3) ADC1 & ADC2 are connectors in (1)(2) to read analog data from an external sensor.

1 PA4 10 PA5 11 PA6 12 PA7 13 PB0 14 PB1 15 VSS 16 VDD 17 PA8 18 PA9 19 PC14 2 PA10 20 PA13 21 PA14 22 PA15 23 PB3 24 PB6 25 PB7 26 BOOT0 27 VSS 28 PC15 3 NRST 4 VDDA

Indicators LEDs that are connected to the pins 18 and 19 of the MCU in (2)(3). (6) LEDs

I2C Pull-Up resistors, pins 25 and 26 of the MCU in (2)(3).

High Speed Crystal Oscillator 16MHz. STM32L031G6U6 Microcontroller. Microcontroller's Section of the BaroAxel Brain PCB.

File: BaroAxel_Brain_STM32_MPU.kicad_sch Sheet: /Microcontroller/ Electro Scientific Club | Mohamed Yanis Hiou

Id: 2/4 Title: BaroAxel Brain PCB | STM32 MCU Section

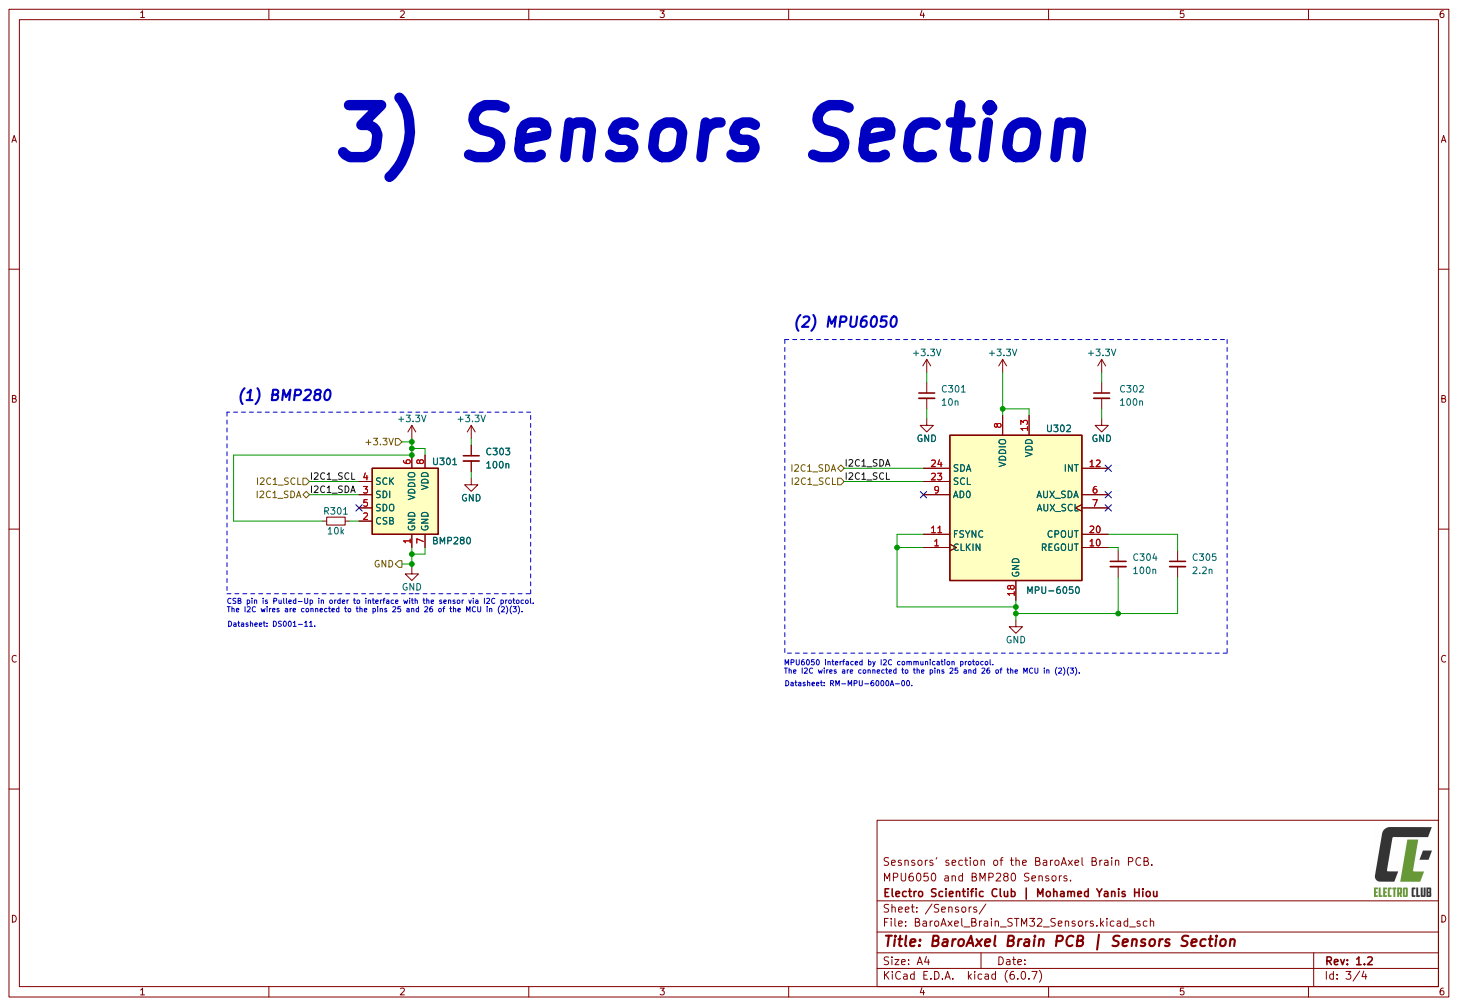
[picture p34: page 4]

1 CSB 2 SDI 3 SCK 4 SDO 5 VDDIO

File: BaroAxel_Brain_STM32_Sensors.kicad_sch Sheet: /Sensors/ Electro Scientific Club | Mohamed Yanis Hiou MPU6050 and BMP280 Sensors. Sesnsors' section of the BaroAxel Brain PCB.

Id: 3/4 Title: BaroAxel Brain PCB | Sensors Section

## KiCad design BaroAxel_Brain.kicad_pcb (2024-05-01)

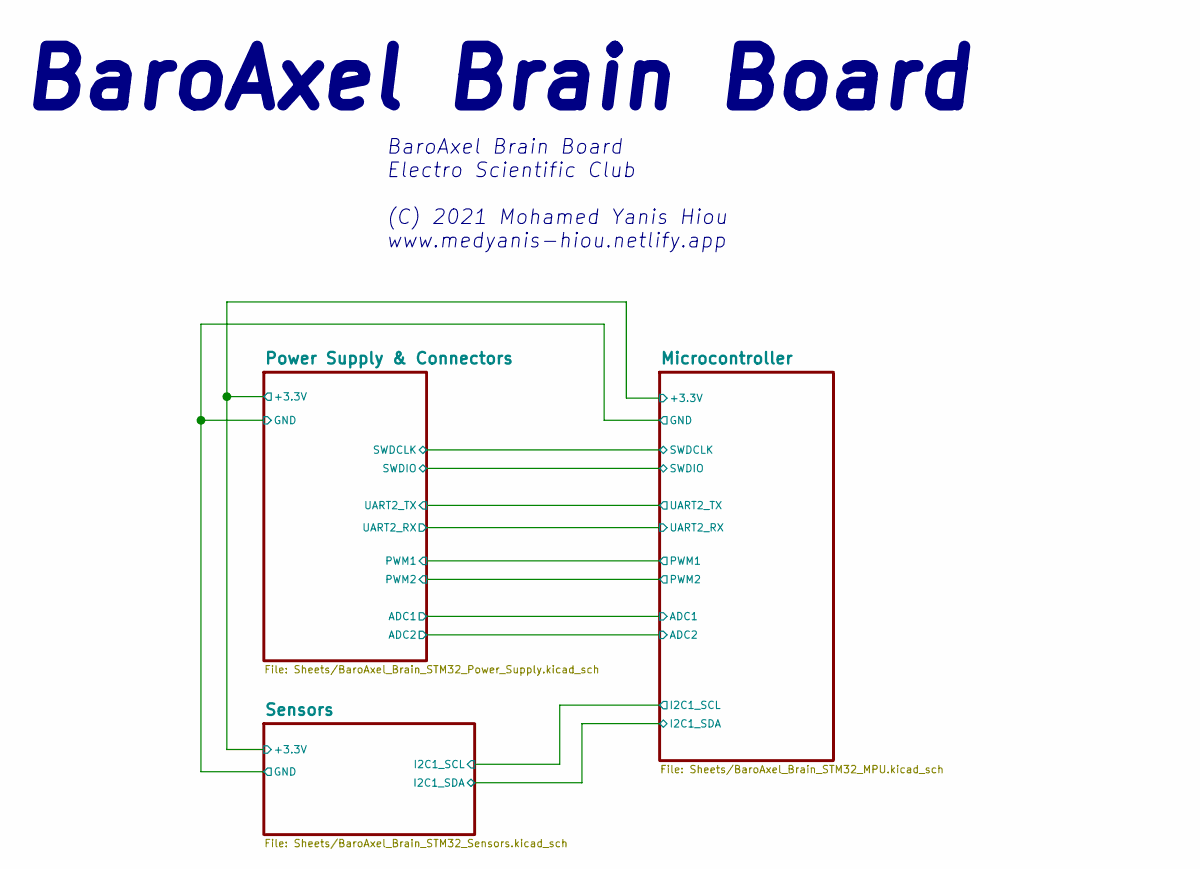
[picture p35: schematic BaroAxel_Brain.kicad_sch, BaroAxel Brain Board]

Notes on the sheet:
BaroAxel Brain Board Electro Scientific Club (C) 2021 Mohamed Yanis Hiou www.medyanis-hiou.netlify.app
BaroAxel Brain Board

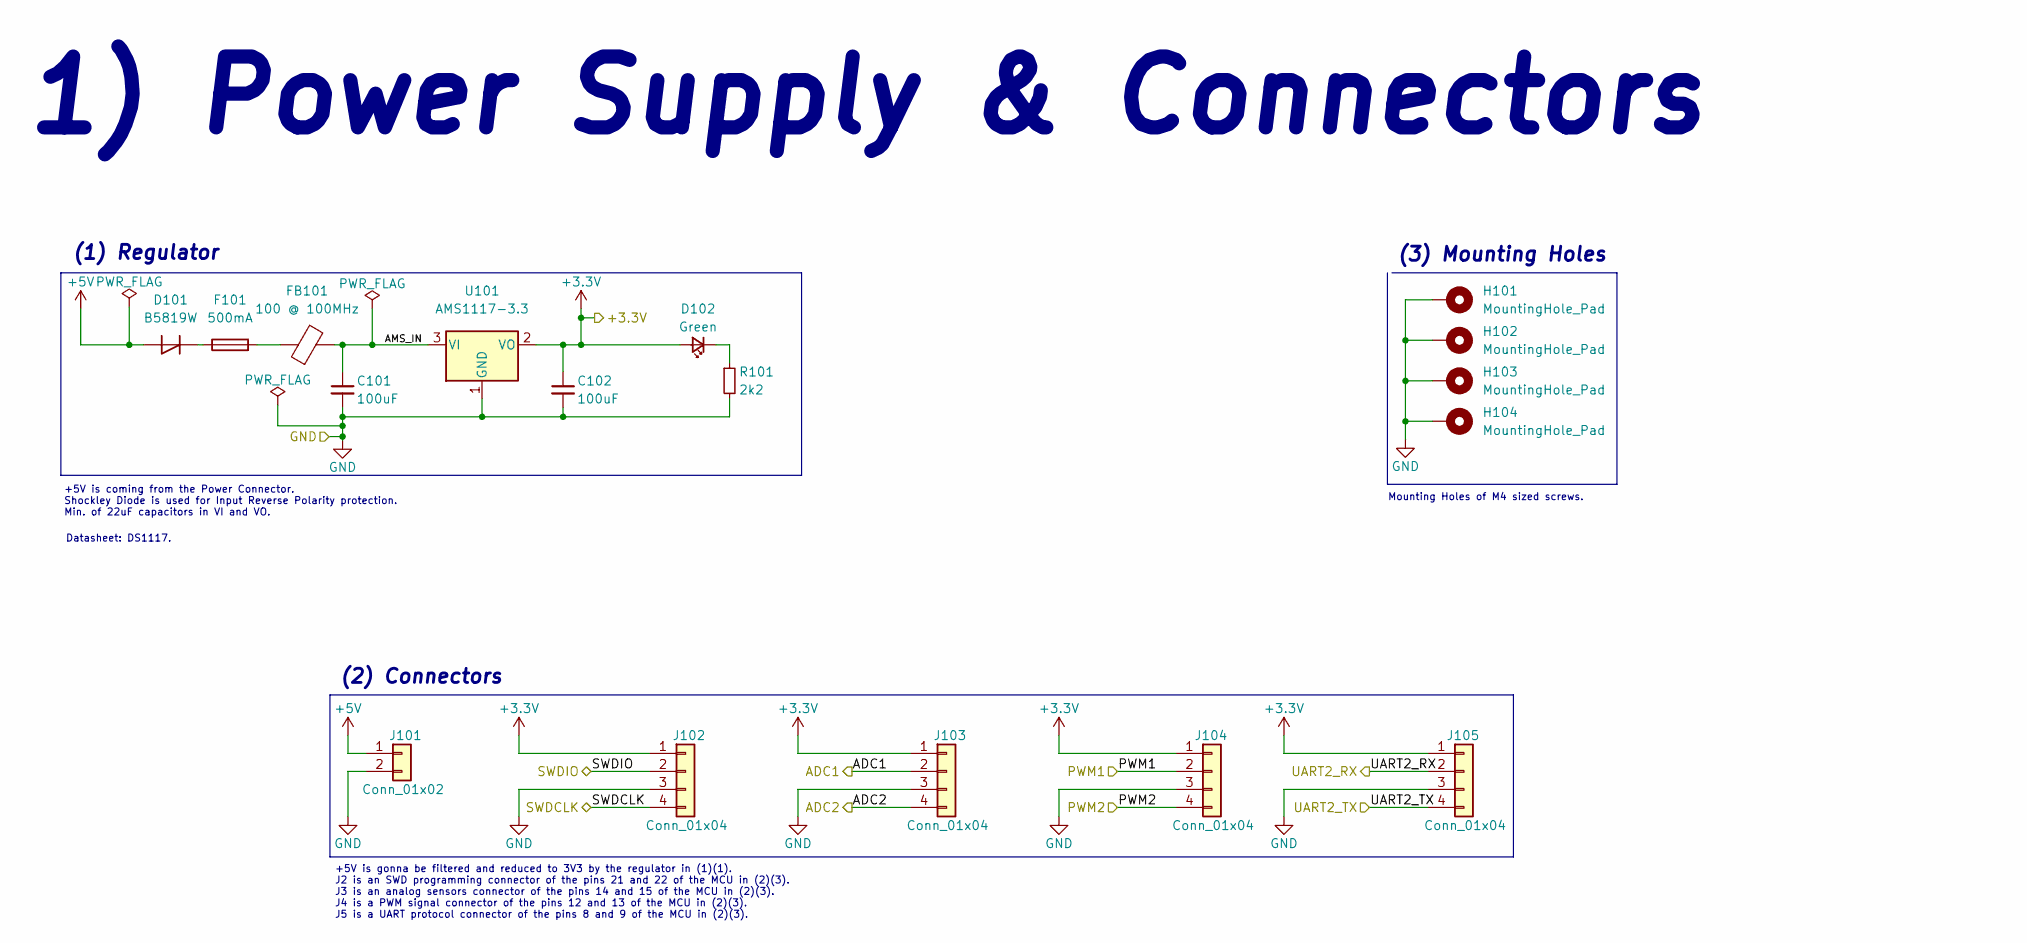
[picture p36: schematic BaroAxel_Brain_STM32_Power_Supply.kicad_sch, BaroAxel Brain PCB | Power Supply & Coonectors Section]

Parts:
C101, C102: 100uF; C_0603_1608Metric
D101: B5819W; D_1206_3216Metric
D102: Green; LED_0603_1608Metric
F101: 500mA; Fuse_0805_2012Metric
FB101: 100 @ 100MHz; L_0603_1608Metric
H101, H102, H103, H104: MountingHole_Pad; MountingHole_4.3mm_M4_Pad_Via
J101: Conn_01x02; JST_XH_S2B-XH-A_1x02_P2.50mm_Horizontal
J102, J103, J104, J105: Conn_01x04; JST_XH_S4B-XH-A_1x04_P2.50mm_Horizontal
R101: 2k2; R_0402_1005Metric
U101: AMS1117-3.3; SOT-223-3_TabPin2

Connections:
+5V: D101.2 (A), J101.1
/Microcontroller/ADC1: J103.2; also elsewhere on the board
/Microcontroller/ADC2: J103.4; also elsewhere on the board
/Microcontroller/PWM1: J104.2; also elsewhere on the board
/Microcontroller/PWM2: J104.4; also elsewhere on the board
/Microcontroller/SWDCLK: J102.4; also elsewhere on the board
/Microcontroller/SWDIO: J102.2; also elsewhere on the board
/Microcontroller/UART2_RX: J105.2; also elsewhere on the board
/Microcontroller/UART2_TX: J105.4; also elsewhere on the board
/Power Supply & Connectors/AMS_IN: C101.1, FB101.2, U101.3 (VI)
unnamed: D101.1 (K), F101.1
unnamed: D102.1 (K), R101.1
unnamed: F101.2, FB101.1

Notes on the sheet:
+5V is coming from the Power Connector. Shockley Diode is used for Input Reverse Polarity protection. Min. of 22uF capacitors in VI and VO.
1) Power Supply & Connectors
Datasheet: DS1117.
(3) Mounting Holes
Mounting Holes of M4 sized screws.
+5V is gonna be filtered and reduced to 3V3 by the regulator in (1)(1). J2 is an SWD programming connector of the pins 21 and 22 of the MCU in (2)(3). J3 is an analog sensors connector of the pins 14 and 15 of the MCU in (2)(3). J4 is a PWM signal connector of the pins 12 and 13 of the MCU in (2)(3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
(1) Regulator
(2) Connectors

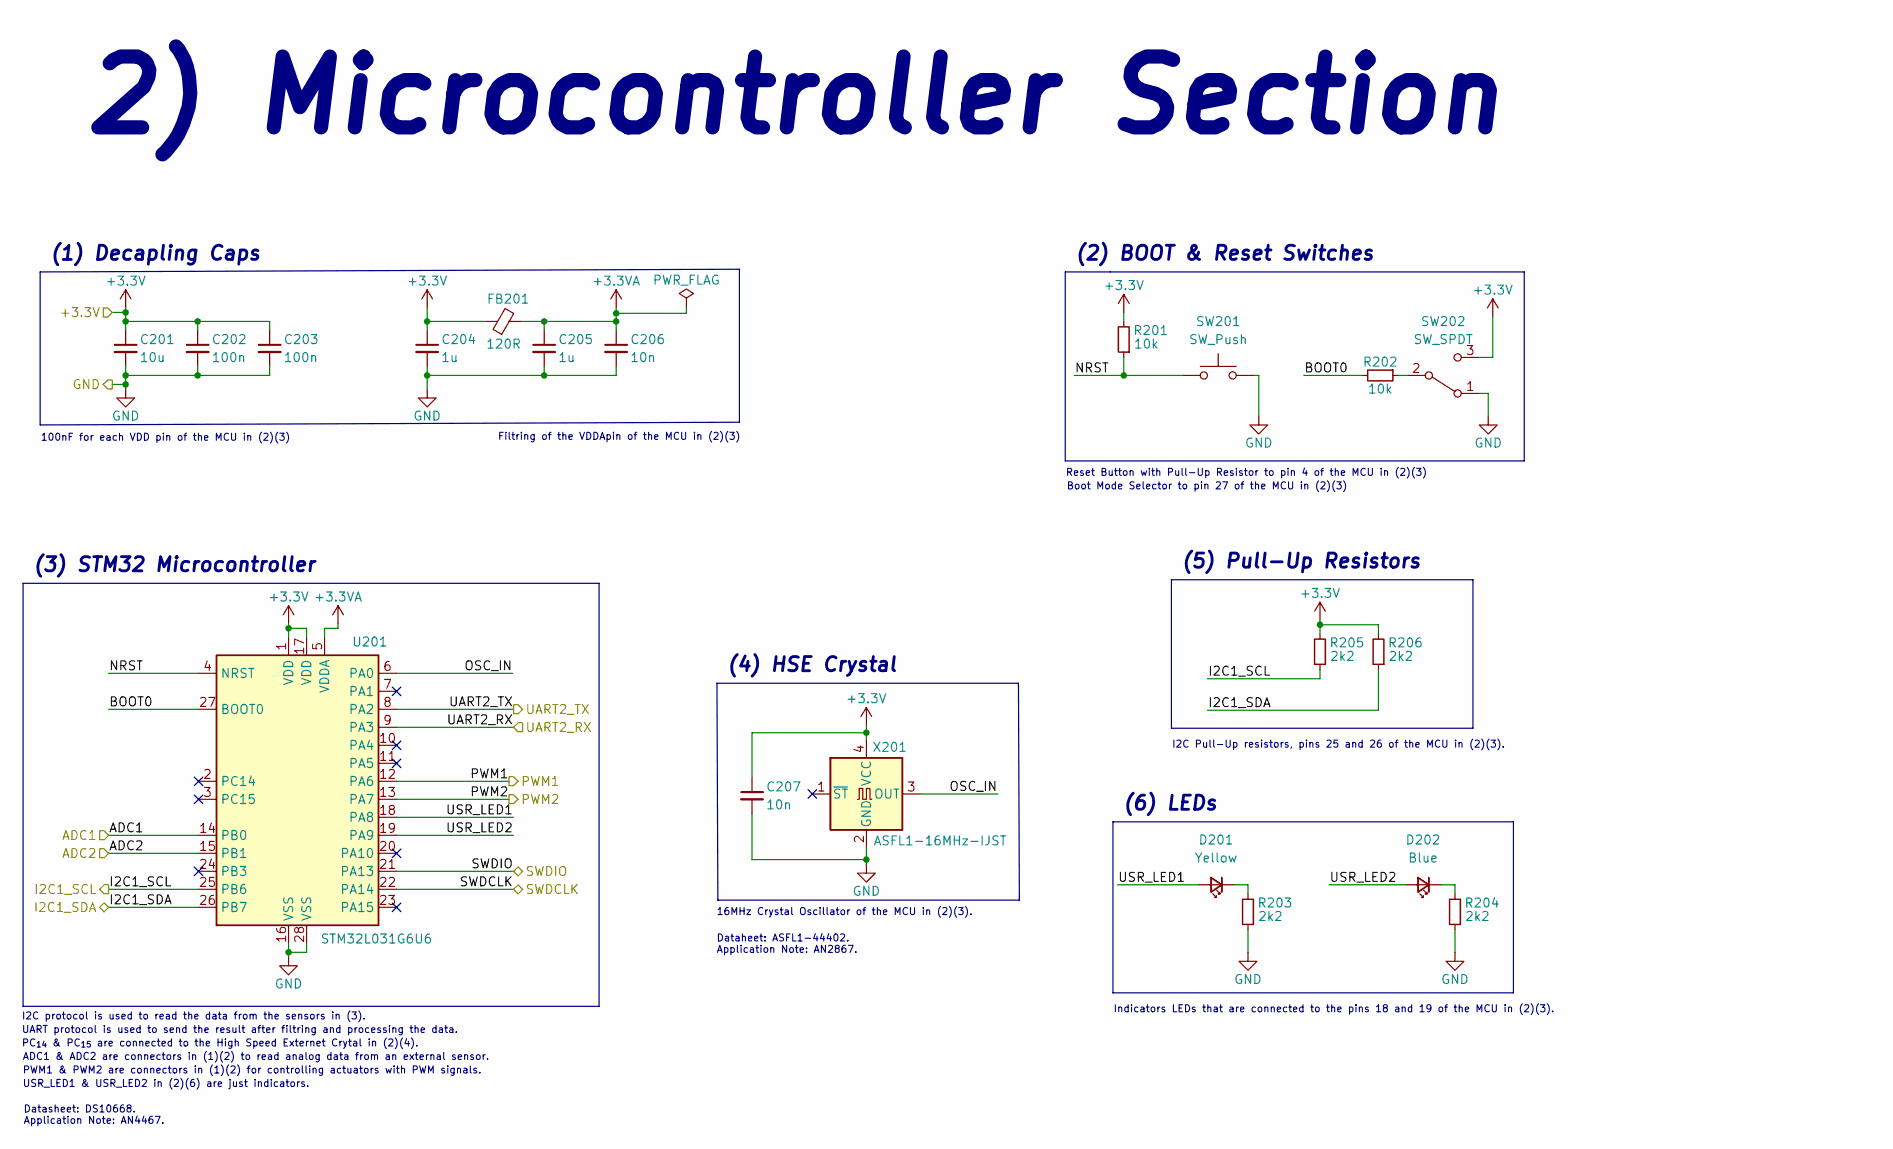
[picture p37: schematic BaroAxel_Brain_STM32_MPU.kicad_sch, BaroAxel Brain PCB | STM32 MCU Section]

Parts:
C201: 10u; C_0402_1005Metric
C202, C203: 100n; C_0402_1005Metric
C204, C205: 1u; C_0402_1005Metric
C206, C207: 10n; C_0402_1005Metric
D201: Yellow; LED_0603_1608Metric
D202: Blue; LED_0603_1608Metric
FB201: 120R; L_0603_1608Metric
R201, R202: 10k; R_0402_1005Metric
R203, R204, R205, R206: 2k2; R_0402_1005Metric
SW201: SW_Push; SW_SPST_B3U-1000P-B
SW202: SW_SPDT; SW_SPDT_PCM12
U201: STM32L031G6U6; QFN-28_4x4mm_P0.5mm
X201: ASFL1-16MHz-IJST; Oscillator_SMD_SeikoEpson_SG8002LB-4Pin_5.0x3.2mm

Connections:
+3.3VA: C205.1, C206.1, FB201.2, U201.5 (VDDA)
/Microcontroller/ADC1: U201.14 (PB0); also elsewhere on the board
/Microcontroller/ADC2: U201.15 (PB1); also elsewhere on the board
/Microcontroller/BOOT0: R202.2, U201.27 (BOOT0)
/Microcontroller/I2C1_SCL: R205.1, U201.25 (PB6); also elsewhere on the board
/Microcontroller/I2C1_SDA: R206.1, U201.26 (PB7); also elsewhere on the board
/Microcontroller/NRST: R201.1, SW201.1, U201.4 (NRST)
/Microcontroller/OSC_IN: U201.6 (PA0), X201.3 (OUT)
/Microcontroller/PWM1: U201.12 (PA6); also elsewhere on the board
/Microcontroller/PWM2: U201.13 (PA7); also elsewhere on the board
/Microcontroller/SWDCLK: U201.22 (PA14); also elsewhere on the board
/Microcontroller/SWDIO: U201.21 (PA13); also elsewhere on the board
/Microcontroller/UART2_RX: U201.9 (PA3); also elsewhere on the board
/Microcontroller/UART2_TX: U201.8 (PA2); also elsewhere on the board
/Microcontroller/USR_LED1: D201.2 (A), U201.18 (PA8)
/Microcontroller/USR_LED2: D202.2 (A), U201.19 (PA9)
unnamed: D201.1 (K), R203.2
unnamed: D202.1 (K), R204.2
unnamed: R202.1, SW202.2 (B)

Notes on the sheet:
I2C Pull-Up resistors, pins 25 and 26 of the MCU in (2)(3).
16MHz Crystal Oscillator of the MCU in (2)(3).
Boot Mode Selector to pin 27 of the MCU in (2)(3)
2) Microcontroller Section
USR_LED1 & USR_LED2 in (2)(6) are just indicators.
Datasheet: DS10668. Application Note: AN4467.
(4) HSE Crystal
UART protocol is used to send the result after filtring and processing the data.
100nF for each VDD pin of the MCU in (2)(3)
(1) Decapling Caps
ADC1 & ADC2 are connectors in (1)(2) to read analog data from an external sensor.
(5) Pull-Up Resistors
Indicators LEDs that are connected to the pins 18 and 19 of the MCU in (2)(3).
(6) LEDs
(2) BOOT & Reset Switches
PC_{14} & PC_{15} are connected to the High Speed Externet Crytal in (2)(4).
PWM1 & PWM2 are connectors in (1)(2) for controlling actuators with PWM signals.
(3) STM32 Microcontroller
I2C protocol is used to read the data from the sensors in (3).
Filtring of the VDDApin of the MCU in (2)(3)
Dataheet: ASFL1-44402. Application Note: AN2867.
Reset Button with Pull-Up Resistor to pin 4 of the MCU in (2)(3)

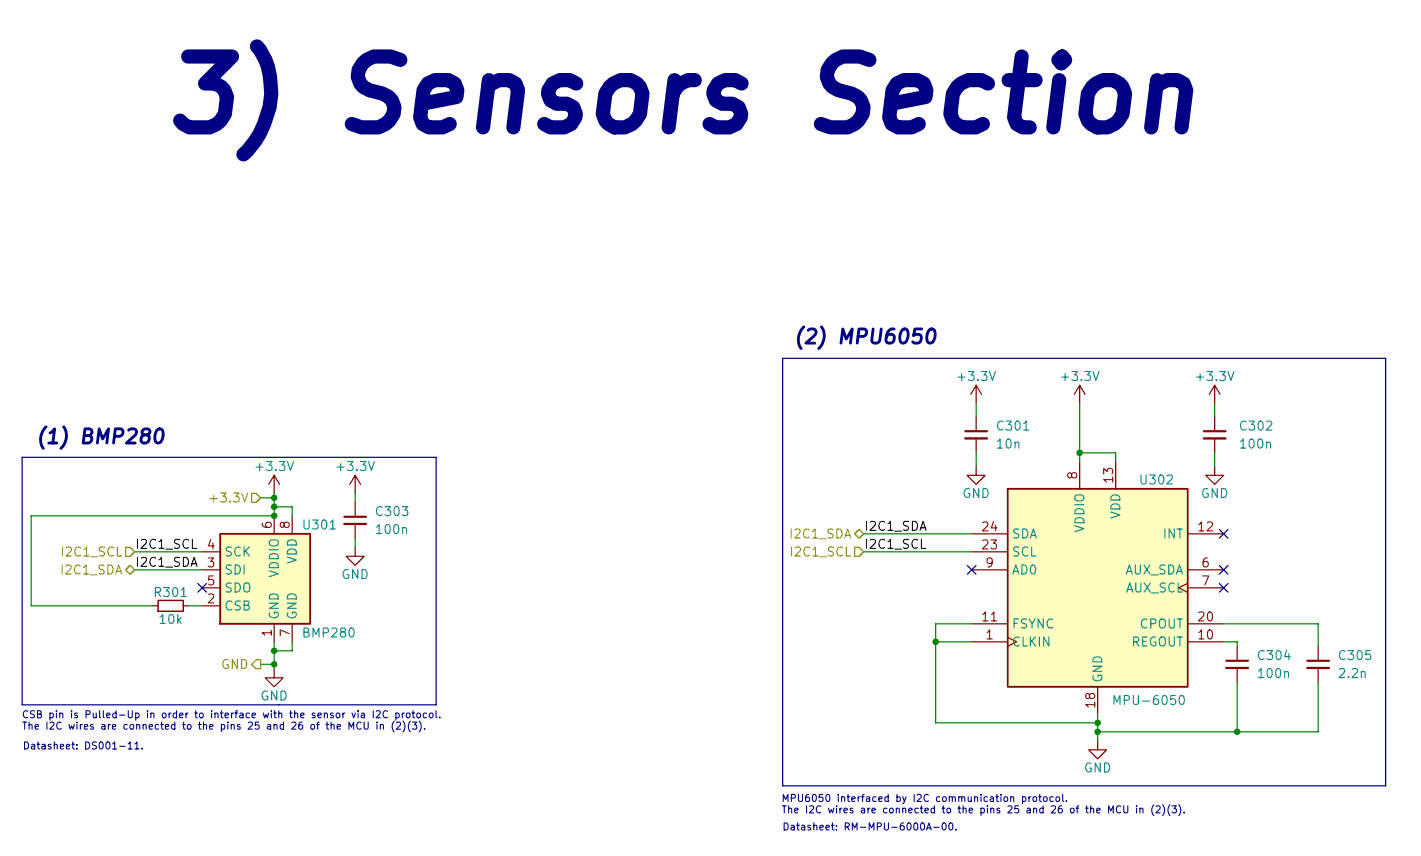
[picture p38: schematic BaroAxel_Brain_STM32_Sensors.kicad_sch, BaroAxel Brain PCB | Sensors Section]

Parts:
C301: 10n; C_0402_1005Metric
C302, C303, C304: 100n; C_0402_1005Metric
C305: 2.2n; C_0402_1005Metric
R301: 10k; R_0402_1005Metric
U301: BMP280; Bosch_LGA-8_2x2.5mm_P0.65mm_ClockwisePinNumbering
U302: MPU-6050; InvenSense_QFN-24_4x4mm_P0.5mm

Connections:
/Microcontroller/I2C1_SCL: U301.4 (SCK), U302.23 (SCL); also elsewhere on the board
/Microcontroller/I2C1_SDA: U301.3 (SDI), U302.24 (SDA); also elsewhere on the board
unnamed: C304.1, U302.10 (REGOUT)
unnamed: C305.1, U302.20 (CPOUT)
unnamed: R301.2, U301.2 (CSB)

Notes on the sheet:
MPU6050 interfaced by I2C communication protocol. The I2C wires are connected to the pins 25 and 26 of the MCU in (2)(3).
Datasheet: RM-MPU-6000A-00.
3) Sensors Section
(2) MPU6050
Datasheet: DS001-11.
CSB pin is Pulled-Up in order to interface with the sensor via I2C protocol. The I2C wires are connected to the pins 25 and 26 of the MCU in (2)(3).
(1) BMP280

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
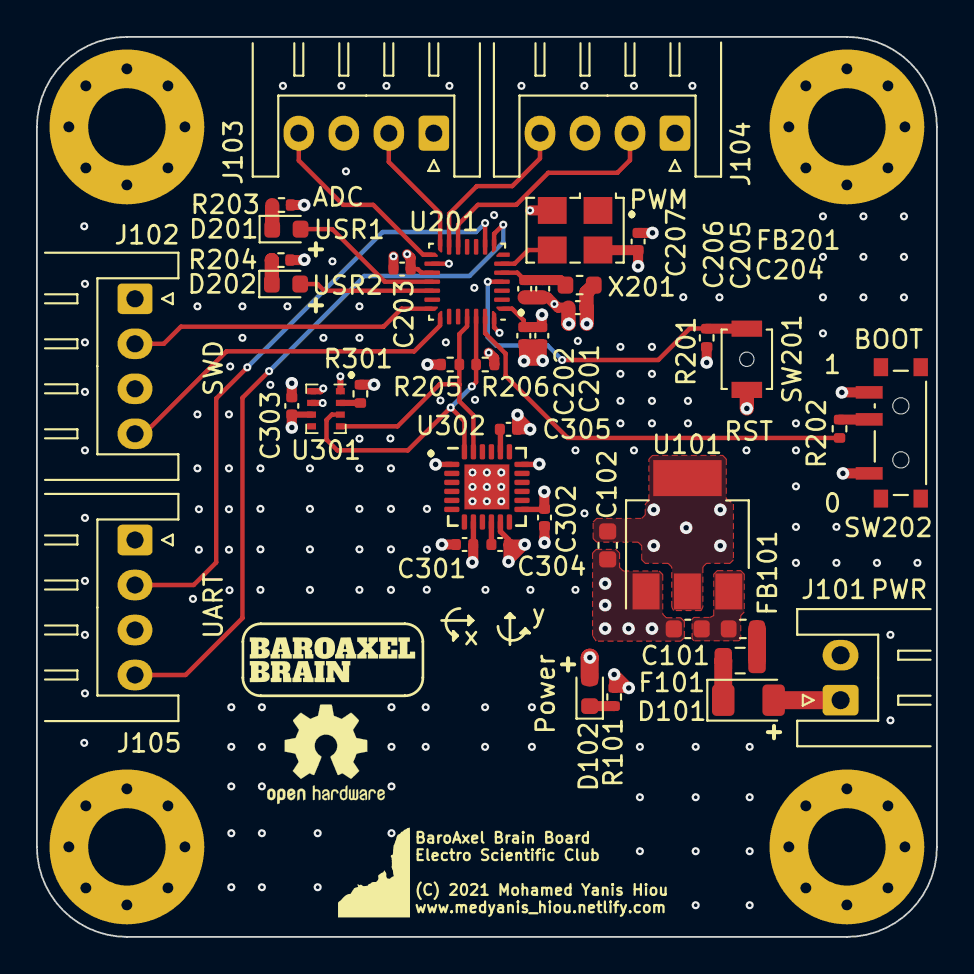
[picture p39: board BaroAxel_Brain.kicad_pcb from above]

Board: 4 copper layers, 50.0 x 50.0 mm, 45 parts (0 on the bottom side), 29 nets.

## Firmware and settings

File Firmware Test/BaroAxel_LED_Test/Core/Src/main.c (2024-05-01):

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
/* Includes ------------------------------------------------------------------*/
#include "main.h"

/* USER CODE BEGIN Includes */
#include "stdio.h"
#include "string.h"
#include "imu.h"

/* USER CODE END Includes */

I2C_HandleTypeDef hi2c1;

UART_HandleTypeDef huart2;

void SystemClock_Config(void);
static void MX_GPIO_Init(void);
static void MX_I2C1_Init(void);
static void MX_USART2_UART_Init(void);
/**
  * @brief  The application entry point.
  * @retval int
  */
int main(void)
{

  /* MCU Configuration--------------------------------------------------------*/

  /* Reset of all peripherals, Initializes the Flash interface and the Systick. */
  HAL_Init();

  /* Configure the system clock */
  SystemClock_Config();

  /* Initialize all configured peripherals */
  MX_GPIO_Init();
  MX_I2C1_Init();
  MX_USART2_UART_Init();
  /* USER CODE BEGIN 2 */

  //MPU6050_Init();

  /* USER CODE END 2 */

  float Ax, Ay, Az, Gx, Gy, Gz;
  char buf[20];
  MPU6050_init();

  char hello[] = "\n\rHello, World!\n\r";

  /* Infinite loop */
  /* USER CODE BEGIN WHILE */
  while (1)
  {
    /* USER CODE END WHILE */

    /* USER CODE BEGIN 3 */

	  MPU6050_Read_Accel(&Ax, &Ay, &Az);
	  MPU6050_Read_Accel(&Gx, &Gy, &Gz);

	  HAL_UART_Transmit(&huart2, hello, strlen(hello), 1000);

	  sprintf(buf, "%f\n", Ax);
	  HAL_UART_Transmit(&huart2, (uint8_t)buf, strlen(buf), 1000);


	  HAL_GPIO_TogglePin(LED1_GPIO_Port, LED1_Pin);
	  HAL_Delay(1000);
	  HAL_GPIO_TogglePin(LED1_GPIO_Port, LED1_Pin);
	  HAL_GPIO_TogglePin(LED2_GPIO_Port, LED2_Pin);
	  HAL_Delay(1000);
	  HAL_GPIO_TogglePin(LED2_GPIO_Port, LED2_Pin);

  }
  /* USER CODE END 3 */
}

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


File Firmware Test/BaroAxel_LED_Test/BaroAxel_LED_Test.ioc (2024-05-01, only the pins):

Mcu.UserName=STM32L031G6Ux
PA0-CK_IN.Signal=RCC_CK_IN
PA10.Signal=I2C1_SDA
PA13.Signal=SYS_SWDIO
PA14.Signal=SYS_SWCLK
PA2.Signal=USART2_TX
PA3.Signal=USART2_RX
PA8.GPIO_Label=LED1
PA8.Signal=GPIO_Output
PA9.GPIO_Label=LED2
PA9.Signal=GPIO_Output
PB6.Signal=I2C1_SCL

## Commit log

2024-05-01 Initial Commit Upload
    [BaroAxel_Brain-B_Cu.gbr, BaroAxel_Brain-B_Mask.gbr, BaroAxel_Brain-B_Paste.gbr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]
2024-06-12 Modifying the Gerber File
    [BaroAxel_Brain-B_Cu.gbr, BaroAxel_Brain-B_Mask.gbr, BaroAxel_Brain-B_Paste.gbr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]

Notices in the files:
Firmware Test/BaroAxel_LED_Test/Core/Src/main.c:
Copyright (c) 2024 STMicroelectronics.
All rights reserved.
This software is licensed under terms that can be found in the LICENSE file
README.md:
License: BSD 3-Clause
